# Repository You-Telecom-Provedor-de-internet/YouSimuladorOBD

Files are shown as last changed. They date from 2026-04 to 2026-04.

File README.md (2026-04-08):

# YouSimuladorOBD - Emulador OBD-II com ESP32

Simulador OBD-II baseado em `ESP32` para validar scanners, adaptadores e aplicativos automotivos reais em bancada e evoluir para uma placa dedicada orientada a produto.

O projeto atual entrega:

- `7` protocolos OBD-II selecionaveis em runtime
- barramento `CAN` validado com scanner real
- barramento `K-Line` validado com `L9637D`
- `Web UI`, `API REST`, `WebSocket`, `mDNS` e `OTA`
- odometro persistente e camada diagnostica com `Mode 02`, `03`, `04`, `06` e `09`

Importante:

- o simulador nao usa Bluetooth proprio nesta revisao
- a validacao de bancada foi feita com adaptadores externos, como `OBDLink MX+` e `ELM327`

## Protocolos suportados

| Enum | Protocolo | Fisica | Estado |
|---|---|---|---|
| `0` | `CAN 11b 500k` | CAN | Validado |
| `1` | `CAN 11b 250k` | CAN | Validado |
| `2` | `CAN 29b 500k` | CAN | Validado |
| `3` | `CAN 29b 250k` | CAN | Validado |
| `4` | `ISO 9141-2` | K-Line | Validado |
| `5` | `KWP 5-baud` | K-Line | Validado |
| `6` | `KWP Fast` | K-Line | Validado |

## Hardware validado

- `ESP32 DevKit` 38 pinos
- `SN65HVD230` para CAN
- `L9637D` para K-Line
- `LM2596` para `12V -> 5V`
- `OLED SH1107 128x128`
- `KY-040`
- `6` botoes + `3` bits de DIP + `3` LEDs de status

## RevA PCB congelada

A `RevA` da placa foi congelada como:

- `carrier para ESP32 DevKit 38 pinos`
- `OLED SH1107` em modulo por header
- `KY-040` em modulo por header
- `LM2596` mantido como modulo ou footprint equivalente de baixo risco

Ou seja, nesta revisao a PCB nao integra `ESP32-WROOM` soldado diretamente. O objetivo e preservar o modulo validado em bancada, reduzir risco da primeira placa e acelerar a ida para layout.

## Fase atual do projeto

Estado atual consolidado:

- prototipo fisico montado e testado com `ESP32 DevKit`, `L9637D`, `SN65HVD230`, `OLED` e interface local
- `7` protocolos suportados com aceite operacional, incluindo `KWP 5-baud`
- arquitetura `RevA` mantida como `carrier para ESP32 DevKit 38 pinos`

Objetivo desta proxima fase:

- capturar e fechar a `PCB RevA`
- reduzir improvisos de bancada e transformar a arquitetura atual em hardware repetivel
- preparar a plataforma para virar produto com foco em robustez eletrica, montagem, teste e manutencao

## Documentacao canonica

Use estes arquivos como ponto de entrada principal:

- [Arquitetura canonica](docs/arquitetura.md)
- [Hardware consolidado](docs/hardware.md)
- [Pinout canonico](docs/pinout.md)
- [Manual de operacao](docs/manual-operacao.md)
- [Montagem K-Line com L9637D](docs/kline-l9637d-montagem.md)
- [Diagrama eletrico e handoff PCB](docs/diagrama-eletrico-pcb.md)
- [RevA carrier para ESP32 DevKit](docs/reva-carrier-esp32-devkit.md)
- [Mapa final de GPIO da RevA](docs/mapa-gpio-reva.md)
- [Guia executivo para PCB](docs/engenharia-pcb.md)
- [Firmware - README local](firmware/README.md)
- [Hardware - README local](hardware/README.md)
- [Esquematico conceitual](hardware/schematic/esquematico-conceitual.md)
- [Netlist humana](hardware/schematic/netlist-humana.md)
- [BOM preliminar](hardware/schematic/bom-preliminar.csv)
- [Requisitos de layout PCB](hardware/pcb/requisitos-layout.md)
- [Hardware - Pacote para PCB](hardware/pcb-handoff/README.md)
- [Hardware - KiCad RevA](hardware/kicad/revA/README.md)

## Build e gravacao

```bash
cd firmware
pio run
pio run -t upload
pio run -t uploadfs
```

Para detalhes do firmware e das dependencias:

- [firmware/README.md](firmware/README.md)

## Como evoluir a RevA para esquematico/PCB real

1. Ler [docs/hardware.md](docs/hardware.md) e [docs/pinout.md](docs/pinout.md).
2. Capturar ou revisar a conectividade com base em:
   - [hardware/schematic/esquematico-conceitual.md](hardware/schematic/esquematico-conceitual.md)
   - [hardware/schematic/netlist-humana.md](hardware/schematic/netlist-humana.md)
   - [hardware/schematic/bom-preliminar.csv](hardware/schematic/bom-preliminar.csv)
3. Aplicar as regras de layout em [hardware/pcb/requisitos-layout.md](hardware/pcb/requisitos-layout.md).
4. Comparar com o handoff congelado em [hardware/pcb-handoff/](hardware/pcb-handoff/).
5. Continuar a captura nativa a partir de [hardware/kicad/revA/](hardware/kicad/revA/).
6. Fechar a `RevA` com criterio de produto:
   - protecao automotiva definitiva
   - conectividade mecanica repetivel
   - pontos de teste
   - montagem e manutencao previsiveis

## Estrutura de pastas

```text
YouSimuladorOBD/
|- README.md
|- assets/
|  `- validation/
|- docs/
|  |- arquitetura.md
|  |- hardware.md
|  |- pinout.md
|  |- manual-operacao.md
|  |- kline-l9637d-montagem.md
|  |- diagrama-eletrico-pcb.md
|  |- reva-carrier-esp32-devkit.md
|  |- mapa-gpio-reva.md
|  |- engenharia-pcb.md
|  `- ota-manifest.example.json
|- firmware/
|  |- README.md
|  |- include/
|  |- src/
|  |- data/
|  `- platformio.ini
|- hardware/
|  |- README.md
|  |- bom/
|  |- cad/
|  |- kicad/revA/
|  |- pcb/
|  |- pcb-handoff/
|  `- schematic/
|- tools/
`- wokwi/
```

## Observacoes importantes

- os documentos canonicos desta rodada sao `docs/hardware.md`, `docs/pinout.md`, `docs/engenharia-pcb.md` e os arquivos em `hardware/schematic/`
- `hardware/pcb-handoff/` e `hardware/kicad/revA/` continuam sendo baseline tecnico importante para o engenheiro de PCB
- os artefatos de validacao de bancada que estavam soltos na raiz foram movidos para `assets/validation/`
- a integracao com o laboratorio Codex permanece no repositorio do plugin `YOU OBD Lab`, separado deste repositorio
- a operacao diaria do simulador, incluindo OTA e credencial fixa da API, esta em `docs/manual-operacao.md`

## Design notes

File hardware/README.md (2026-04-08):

# Hardware

Este diretorio concentra os artefatos de hardware, mecanica, handoff e EDA do `YouSimuladorOBD`.

## Baseline da RevA

A `RevA` atual deve ser entendida como:

- `carrier para ESP32 DevKit 38 pinos`
- `SN65HVD230` para CAN
- `L9637D` para K-Line
- `OLED SH1107` via header
- `KY-040` via header
- buck `12V -> 5V` de baixo risco baseado em `LM2596` ou equivalente

## Funcao das pastas

### `kicad/`

- bootstrap EDA nativo da `RevA`
- referencia para continuar a captura do esquematico real

### `pcb-handoff/`

- netlist e BOM de handoff congeladas em CSV
- baseline de transicao entre bancada e captura formal em EDA

### `schematic/`

- material textual canonico desta rodada
- contem:
  - `esquematico-conceitual.md`
  - `netlist-humana.md`
  - `bom-preliminar.csv`

### `pcb/`

- regras e requisitos de layout para a placa

### `cad/`

- referencia mecanica e arquivos de case/painel

### `bom/`

- registros auxiliares de status de BOM

## Fluxo recomendado para engenharia

1. comecar por `../docs/hardware.md`
2. ler `../docs/pinout.md`
3. usar `schematic/` como base textual atual
4. comparar com `pcb-handoff/`
5. continuar a captura em `kicad/revA/`

## Observacao importante

O fato de algo existir em `hardware/` nao significa automaticamente que esteja confirmado pelo firmware.

Para classificacao tecnica, usar a regra:

- `confirmado no codigo`
- `confirmado na documentacao/EDA existente`
- `inferido / hipotese`

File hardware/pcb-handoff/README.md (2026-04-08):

# Pacote de Handoff para PCB

Este diretorio contem o material tecnico consolidado para o engenheiro capturar o esquema da placa.

## Arquivos

- `netlist-rev-a.csv`
  - nets eletricas consolidadas
- `bom-rev-a.csv`
  - lista base de componentes para a revisao A

## Documento mestre

O documento principal do handoff e:

- `docs/diagrama-eletrico-pcb.md`
- `docs/engenharia-pcb.md`

## Captura nativa iniciada

O projeto tambem ja possui um bootstrap nativo no `KiCad`:

- `hardware/kicad/revA/YouSimuladorOBD_RevA.kicad_sch`

Esse conjunto nao substitui o handoff consolidado, mas acelera a continuacao da captura pelo engenheiro.

## Escopo

Este pacote descreve a topologia eletrica validada em bancada:

- `ESP32 DevKit 38 pinos` em carrier RevA
- `LM2596`
- `SN65HVD230`
- `L9637D`
- `OLED`
- botoes, encoder, DIP e LEDs

## Decisao congelada da RevA

A revisao `RevA` fica congelada como:

- `carrier para ESP32 DevKit 38 pinos`
- `OLED` via header
- `KY-040` via header
- `LM2596` por modulo ou footprint equivalente

O pacote desta pasta e o bootstrap em `KiCad` devem ser interpretados nessa arquitetura.

## Observacao importante

Este pacote complementa `hardware/schematic/` e o bootstrap em `hardware/kicad/revA/`; os tres devem permanecer coerentes com os documentos canonicos em `docs/`.

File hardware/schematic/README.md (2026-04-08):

# Material Canonico de Esquematico

Esta pasta agora e o ponto canonico dos artefatos textuais de esquematico do projeto.

## Use esta pasta para

- `esquematico-conceitual.md`
  - esquematico textual por blocos da `RevA`
- `netlist-humana.md`
  - conectividade humana consolidada para engenharia
- `bom-preliminar.csv`
  - lista preliminar de componentes para captura e layout

## Fontes principais a usar junto com esta pasta

- `docs/hardware.md`
- `docs/pinout.md`
- `docs/engenharia-pcb.md`
- `hardware/pcb-handoff/`
- `hardware/kicad/revA/`

## Regra pratica

Para divergencias ou duvidas de engenharia:

1. priorizar firmware atual para pinagem e dependencias logicas
2. priorizar `docs/hardware.md` e `docs/pinout.md` para documentacao canonica
3. usar `hardware/pcb-handoff/` e `hardware/kicad/revA/` como baseline de handoff e EDA

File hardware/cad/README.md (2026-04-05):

# CAD e Impressao 3D

Este diretorio concentra os primeiros ativos mecanicos do projeto.

## Primeira peca teste

`bench_case_revA_base`

Objetivo:

- servir como primeira peca de validacao na `Creality K1`
- testar tolerancias, rigidez e volume util para a futura placa do `YouSimuladorOBD`
- oferecer uma base aberta tipo `bench tray`, mais segura para a fase atual do hardware do que um gabinete fechado definitivo

Arquivos gerados:

- `freecad/bench_case_revA_base.FCStd`
- `freecad/bench_case_revA_base.step`
- `freecad/bench_case_revA_base.stl`
- `renders/bench_case_revA_base.png`

## Segunda peca teste

`bench_case_revA_lid_ui`

Objetivo:

- criar a tampa inicial para a bandeja `revA`
- aproximar o frontal do hardware real da UI local
- testar leitura do `OLED SH1107 128x128` atraves de uma janela quadrada
- testar a disposicao real de botoes dedicados e do encoder rotativo

Arquivos gerados:

- `freecad/bench_case_revA_lid_ui.FCStd`
- `freecad/bench_case_revA_lid_ui.step`
- `freecad/bench_case_revA_lid_ui.stl`
- `renders/bench_case_revA_lid_ui.png`

Caracteristicas:

- tampa tipo `cap` com labio interno de encaixe
- janela quadrada central para `OLED SH1107 128x128`
- rebaixo frontal ao redor do display
- fileira de 6 botoes: `PREV`, `NEXT`, `UP`, `DOWN`, `OK`, `PROTO`
- furo separado para o encoder rotativo `KY-040`
- geometria ainda parametrica, mas agora alinhada com a UI implementada no firmware

## Compatibilidade com o projeto real

O handoff eletrico da PCB ja inclui o display e o encoder:

- `hardware/pcb-handoff/bom-rev-a.csv`
  - `DISP1 = OLED SH1107 128x128`
  - `ENC1 = Rotary encoder KY-040`
- `hardware/pcb-handoff/netlist-rev-a.csv`
  - `ENC_A`, `ENC_B`, `ENC_SW`
  - `I2C_SDA`, `I2C_SCL`

Ou seja, esta tampa passa a refletir melhor o que a placa real devera acomodar.

## Assuncoes desta revisao

Como a PCB final ainda esta em captura, esta primeira peca usa um envelope mecanico conservador:

- area util de placa: `120 x 85 mm`
- folga interna lateral: `3 mm`
- espessura da base: `3 mm`
- espessura de parede: `3 mm`
- altura de parede: `22 mm`
- standoffs internos para parafuso `M3`

Isso torna a peca util como:

- bandeja de bancada para a eletronica atual
- base de teste de impressao
- ponto de partida para o gabinete final da PCB

## Ferramentas usadas

- `FreeCAD 1.1`
- `Blender 5.1` para preview

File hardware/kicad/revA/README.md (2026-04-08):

# KiCad RevA

Bootstrap nativo do projeto no `KiCad`, criado a partir do handoff validado em bancada.

## Escopo desta captura inicial

Esta revisao ainda nao e o esquematico completo final. Ela entrega:

- folha raiz nativa do `KiCad`
- separacao por blocos funcionais
- pontos de entrada claros para o engenheiro continuar a captura
- referencia mecanica do frontal de `OLED + KY-040 + 6 botoes`
- arquitetura congelada da `RevA` como `carrier para ESP32 DevKit 38 pinos`

## Arquivos

- `YouSimuladorOBD_RevA.kicad_sch`
  - folha raiz
- `power_input.kicad_sch`
  - entrada OBD, fusivel e buck
- `esp32_core.kicad_sch`
  - MCU, GPIOs e mapa funcional
- `obd_transceivers.kicad_sch`
  - `SN65HVD230` e `L9637D`
- `ui_local.kicad_sch`
  - `OLED SH1107`, `KY-040`, botoes, DIP e LEDs
- `ui-panel-reference.csv`
  - coordenadas base do painel frontal da tampa de teste
- `esp32-devkit38-carrier-reference.csv`
  - envelope, headers e keepouts do `ESP32 DevKit` na carrier
- `erc-report.txt`
  - validacao inicial do bootstrap com `0` erros e `0` warnings

## Fonte tecnica

Os dados eletricos consolidados continuam sendo:

- `docs/diagrama-eletrico-pcb.md`
- `docs/reva-carrier-esp32-devkit.md`
- `docs/mapa-gpio-reva.md`
- `hardware/pcb-handoff/netlist-rev-a.csv`
- `hardware/pcb-handoff/bom-rev-a.csv`

## Observacao

Esta captura foi iniciada para que o engenheiro ja possa trabalhar em arquivo EDA nativo sem depender apenas do handoff em `Markdown + CSV`.

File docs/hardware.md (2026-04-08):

# Hardware Consolidado

Documento canonico de consolidacao eletrica do `YouSimuladorOBD`.

Objetivo:

- reunir em um unico lugar o que o firmware realmente exige do hardware
- separar o que esta confirmado no codigo do que vem de documentacao e EDA existente
- registrar explicitamente o que ainda e inferido ou depende de confirmacao antes do esquematico final

Fontes principais usadas nesta consolidacao:

- `firmware/include/config.h`
- `firmware/src/main.cpp`
- `firmware/src/protocols/can_protocol.cpp`
- `firmware/src/protocols/kline_protocol.cpp`
- `firmware/src/protocols/protocol_init.cpp`
- `firmware/src/web/ui_init.cpp`
- `firmware/src/web/web_server.cpp`
- `firmware/platformio.ini`
- `docs/pinout.md`
- `docs/kline-l9637d-montagem.md`
- `docs/diagrama-eletrico-pcb.md`
- `docs/engenharia-pcb.md`
- `docs/reva-carrier-esp32-devkit.md`
- `docs/mapa-gpio-reva.md`
- `hardware/pcb-handoff/bom-rev-a.csv`
- `hardware/pcb-handoff/netlist-rev-a.csv`
- `hardware/kicad/revA/README.md`
- `hardware/kicad/revA/erc-report.txt`
- `hardware/kicad/revA/*.kicad_sch`
- `wokwi/diagram.json`

## Visao geral funcional da placa

O `YouSimuladorOBD` e uma placa de bancada para emular uma ECU OBD-II usando um `ESP32 DevKit` 38 pinos como MCU principal. A placa precisa responder a scanners reais nos barramentos:

- `CAN` usando o controlador `TWAI` nativo do ESP32 e um transceiver `SN65HVD230`
- `K-Line` usando `UART1` do ESP32 e um transceiver `L9637D`

Tambem precisa oferecer:

- interface local com `OLED SH1107 128x128`
- `6 botoes`
- `encoder KY-040`
- `DIP switch` de 3 bits para selecao rapida de protocolo
- `LED_TX` externo opcional e o LED onboard do DevKit
- `Wi-Fi`, `Web UI`, `WebSocket`, `API REST`, `mDNS` e `OTA` pela rede

Arquitetura alvo desta rodada:

- `RevA` congelada como `carrier board para ESP32 DevKit 38 pinos`
- sem migracao para `ESP32-WROOM` integrado nesta rodada

## Blocos funcionais

| Bloco | Descricao | Classificacao dominante |
|---|---|---|
| MCU | `ESP32 DevKit` 38 pinos com FreeRTOS/Arduino, TWAI, UART1, I2C, Wi-Fi e LittleFS | confirmado no codigo + confirmado na documentacao/EDA existente |
| Entrada automotiva | `OBD-II J1962` com `+12V`, `GND`, `CANH`, `CANL`, `K-Line` | confirmado na documentacao/EDA existente |
| Fonte primaria | `+12V OBD -> fusivel -> buck 12V para 5V` | confirmado na documentacao/EDA existente |
| Fonte logica | `5V` para `VIN` do DevKit e `+3V3_AUX` dedicado para perifericos | confirmado na documentacao/EDA existente |
| CAN | `SN65HVD230` em `+3V3_AUX` ligado ao TWAI nativo do ESP32 | confirmado no codigo + confirmado na documentacao/EDA existente |
| K-Line | `L9637D` com `VS` em `+12V`, logica em `+3V3_AUX`, `K` no OBD e bias passivo dedicado | confirmado no codigo + confirmado na documentacao/EDA existente |
| UI local | `OLED SH1107`, `KY-040`, `6 botoes`, `DIP`, `LED_TX` opcional | confirmado no codigo + confirmado na documentacao/EDA existente |
| Rede e web | `Wi-Fi AP/STA`, `mDNS`, `ESPAsyncWebServer`, `LittleFS`, `OTA` | confirmado no codigo |
| EDA baseline | handoff em CSV e bootstrap em `KiCad RevA` com `0` erros e `0` warnings de ERC | confirmado na documentacao/EDA existente |

## Entradas

| Entrada | Origem | Observacao | Classificacao |
|---|---|---|---|
| `+12V_OBD` | `J1 pin 16` | alimenta o buck e o `VS` do `L9637D` | confirmado na documentacao/EDA existente |
| `GND` | `J1 pin 4` e `J1 pin 5` | referencia comum do sistema | confirmado na documentacao/EDA existente |
| `CANH/CANL` | `J1 pin 6` e `J1 pin 14` | trafego OBD sobre CAN | confirmado na documentacao/EDA existente |
| `K-Line` | `J1 pin 7` | trafego OBD em `ISO 9141-2`, `KWP 5-baud` e `KWP Fast` | confirmado no codigo + confirmado na documentacao/EDA existente |
| botoes locais | `GPIO32`, `33`, `25`, `26`, `27`, `18` | entradas com `INPUT_PULLUP`, botoes para `GND` | confirmado no codigo |
| encoder | `GPIO14`, `13`, `19` | `A`, `B` e `SW` | confirmado no codigo |
| DIP de protocolo | `GPIO34`, `35`, `36` | somente entrada; exigem pull-up externo para `+3V3_AUX` | confirmado no codigo + confirmado na documentacao/EDA existente |
| USB do DevKit | conector do modulo comercial | usado para gravacao e serial debug | confirmado na documentacao/EDA existente |

## Saidas

| Saida | Destino | Observacao | Classificacao |
|---|---|---|---|
| resposta OBD em CAN | scanner no `J1 pin 6/14` | via `SN65HVD230` | confirmado no codigo + confirmado na documentacao/EDA existente |
| resposta OBD em K-Line | scanner no `J1 pin 7` | via `L9637D` | confirmado no codigo + confirmado na documentacao/EDA existente |
| display local | modulo `OLED SH1107` | I2C em `GPIO21/22` | confirmado no codigo + confirmado na documentacao/EDA existente |
| LED de status externo | `GPIO23` | `LED_TX` opcional para trafego | confirmado no codigo + confirmado na documentacao/EDA existente |
| LED heartbeat | `GPIO2` | LED onboard do DevKit, nao detalhado na carrier | confirmado no codigo |
| Wi-Fi/web | AP/STA com web UI, API e OTA | interface sem fio do ESP32 | confirmado no codigo |

## Interfaces externas

| Interface | Implementacao | Status |
|---|---|---|
| `OBD-II J1962` | `J1` com pinos `4/5/6/7/14/16` usados | confirmado na documentacao/EDA existente |
| `CAN` | `TWAI` do ESP32 + `SN65HVD230` | confirmado no codigo + confirmado na documentacao/EDA existente |
| `K-Line` | `UART1` do ESP32 + `L9637D` | confirmado no codigo + confirmado na documentacao/EDA existente |
| `I2C` | `GPIO21 SDA` e `GPIO22 SCL` para o OLED | confirmado no codigo |
| `USB serial/programacao` | USB do `ESP32 DevKit` | confirmado na documentacao/EDA existente |
| `Wi-Fi 2.4 GHz` | AP/STA do ESP32 | confirmado no codigo |
| `mDNS` | hostname configuravel, default `youobd.local` | confirmado no codigo |
| `BLE/Bluetooth embarcado` | nao usado nesta revisao | confirmado no codigo por ausencia de uso ativo no build e no firmware atual |

## Alimentacao

### Topologia consolidada

```text
J1 pin 16 (+12V OBD)
  -> F1
  -> +12V_PROT
  -> U1 buck 12V -> 5V
  -> U3 L9637D pin 7 (VS)
  -> RK1 510R para a linha K
  -> RLI1 10k para o pino LI do L9637D

J1 pin 4 / pin 5 (GND)
  -> GND comum

U1 OUT+
  -> +5V_SYS
  -> VIN / 5V do ESP32 DevKit
  -> U4 regulador 3.3V dedicado

U4 OUT
  -> +3V3_AUX
  -> U2 SN65HVD230
  -> U3 L9637D VCC logico
  -> OLED SH1107
  -> ENC1 KY-040
  -> pull-ups do DIP
```

### Observacoes

- O firmware depende implicitamente de o `ESP32 DevKit` receber `5V` em `VIN` e do rail `+3V3_AUX` alimentar os perifericos de forma estavel.
- `+3V3_AUX` deve permanecer separado do pino `3V3` de saida do `ESP32 DevKit`.
- O codigo nao define nenhuma medicao de tensao de entrada nem supervisao analogica da fonte. Logo, a robustez da entrada `+12V` fica a cargo da eletrica da placa.
- A corrente total do sistema nao esta formalizada em documento eletrico fechado; isso ainda precisa ser confirmado antes do esquematico final se houver mudanca de buck ou integracao futura do MCU.

## Protecao eletrica

| Item | Estado | Origem | Observacao |
|---|---|---|---|
| `F1` fusivel de entrada `1A` | confirmado como baseline de handoff | docs + `hardware/pcb-handoff` + KiCad bootstrap | nao ha part number final congelado |
| TVS na entrada `+12V` | recomendado e registrado | `docs/diagrama-eletrico-pcb.md` e `docs/engenharia-pcb.md` | nao confirmado como implementado na bancada base |
| protecao contra inversao de polaridade | recomendada | `docs/diagrama-eletrico-pcb.md` | topologia final nao fechada |
| ESD no conector OBD | nao encontrado como item fechado | inferido / hipotese | recomendavel para PCB automotiva, principalmente nas linhas externas |
| terminacao CAN `120R` por jumper ou DNP | recomendada | docs + `hardware/pcb-handoff/bom-rev-a.csv` | nao ha prova no codigo; no breakout de bancada a terminacao pode ja existir |
| desacoplamento local do `L9637D` | confirmado | docs + `hardware/pcb-handoff` + KiCad bootstrap | `CK1` e `CK2` de `100nF` obrigatorios |
| desacoplamento local do `SN65HVD230` | confirmado como baseline de handoff | `hardware/pcb-handoff/bom-rev-a.csv` | `CCAN1 100nF` |

### Fechamento recomendado de protecao para a RevA

Os itens abaixo nao estao confirmados no codigo. Eles sao recomendacoes de engenharia para transformar a `RevA` em uma PCB mais robusta e mais objetiva para compra e montagem.

| Funcao | Componente recomendado | Classificacao | Observacao pratica |
|---|---|---|---|
| fusivel de entrada | `F1 1A` | confirmado na documentacao/EDA existente + recomendacao de fechamento | manter como primeira barreira da linha `+12V_OBD` |
| TVS da entrada `+12V` | `SMCJ24A` unidirecional | inferido / hipotese fortemente recomendada | encapsulamento `DO-214AB`; fica antes do buck e do `VS` do `L9637D` |
| ESD para `CANH/CANL` | `PESD2CAN24LT-Q` | inferido / hipotese fortemente recomendada | componente automotivo de 2 linhas; colocar junto de `J1` |
| ESD/surge para `K-Line` | `ESDLIN1524BJ` | inferido / hipotese fortemente recomendada | otimizado para barramentos tipo `LIN/CXPI`; serve bem como referencia para a linha `K` |
| reversao de polaridade / load disconnect | `LM74502-Q1` + `2 x MOSFET N` back-to-back | inferido / hipotese fortemente recomendada | solucao de baixa perda para uso automotivo; os MOSFETs ainda precisam ser fechados pela corrente alvo |

Observacoes:

- Para prototipo rapido de bancada, um diodo Schottky em serie pode funcionar como protecao simples de reversao, mas nao e a recomendacao principal para a PCB final por perda termica e queda de tensao.
- As protecoes acima devem ser tratadas como adicao recomendada sobre o baseline atual de bancada/handoff, nao como itens ja comprovados pelo firmware.

## Componentes provaveis

| RefDes | Componente provavel | Papel | Classificacao |
|---|---|---|---|
| `MCU1` | `ESP32 DevKit 38p` | MCU principal | confirmado na documentacao/EDA existente |
| `U1` | modulo `LM2596` ou buck equivalente | `12V -> 5V` | confirmado na documentacao/EDA existente |
| `U4` | regulador `3.3V` dedicado | gera `+3V3_AUX` para perifericos | confirmado na documentacao/EDA existente |
| `U2` | `SN65HVD230` | transceiver CAN 3V3 | confirmado na documentacao/EDA existente |
| `U3` | `L9637D` | transceiver K-Line | confirmado na documentacao/EDA existente |
| `TVS1` | `SMCJ24A` | protecao de surto na entrada `+12V` | inferido / hipotese fortemente recomendada |
| `D_ESD_CAN1` | `PESD2CAN24LT-Q` | protecao ESD de `CANH/CANL` | inferido / hipotese fortemente recomendada |
| `D_ESD_K1` | `ESDLIN1524BJ` | protecao ESD/surge da `K-Line` | inferido / hipotese fortemente recomendada |
| `UREV1` | `LM74502-Q1` + MOSFETs externos | protecao de reversao de polaridade e chaveamento de entrada | inferido / hipotese fortemente recomendada |
| `J1` | conector `OBD-II` 16 pinos | interface automotiva externa | confirmado na documentacao/EDA existente |
| `DISP1` | modulo `OLED SH1107 128x128` | interface local | confirmado na documentacao/EDA existente |
| `ENC1` | `KY-040` | encoder da UI | confirmado na documentacao/EDA existente |
| `SW1` | DIP switch 3 posicoes | boot fallback de protocolo | confirmado na documentacao/EDA existente |
| `SW2-SW7` | botoes momentaneos | UI local | confirmado na documentacao/EDA existente |
| `D3` | LED externo opcional | `LED_TX` | confirmado na documentacao/EDA existente |
| `JMCU1/JMCU2` | headers femea `1x19` | carrier do DevKit | confirmado na documentacao/EDA existente |
| `JDISP1` | header `1x4` | modulo OLED | confirmado na documentacao/EDA existente |
| `JENC1` | header `1x5` | modulo encoder | confirmado na documentacao/EDA existente |

## Dependencias eletricas implicitas

Estas dependencias nao dependem de preferencia de software; elas sao impostas pelo hardware ou pelo proprio firmware atual.

1. `GPIO34`, `GPIO35` e `GPIO36` sao somente entrada e sem `pull-up` interno.
   - efeito: o `DIP` precisa de `pull-up` externo para `+3V3_AUX`
   - base: `config.h`, `main.cpp`, `docs/pinout.md`, `hardware/pcb-handoff/netlist-rev-a.csv`

2. A linha `K-Line` precisa de nivel de idle alto estavel em `+12V`.
   - efeito: `RK1 510R` entre `K` e `VS` e `RLI1 10k` entre `LI` e `VS` deixam de ser opcionais para reproduzir a bancada validada
   - base: `docs/kline-l9637d-montagem.md`, `docs/diagrama-eletrico-pcb.md`, `hardware/pcb-handoff`

3. O `L9637D` precisa de dois dominios de alimentacao.
   - `VCC` logico em `+3V3_AUX`
   - `VS` automotivo em `+12V`
   - base: `docs/kline-l9637d-montagem.md`, `docs/diagrama-eletrico-pcb.md`, `hardware/pcb-handoff/netlist-rev-a.csv`

4. O `SN65HVD230` precisa operar em `+3V3_AUX` e ficar com `RS` em `GND` para o modo rapido registrado no handoff.
   - base: `docs/pinout.md`, `hardware/pcb-handoff/netlist-rev-a.csv`

5. A regiao de antena do `ESP32 DevKit` exige `keepout` de cobre e componentes.
   - base: `docs/reva-carrier-esp32-devkit.md`

6. O `OLED` depende de barramento `I2C` em `400 kHz` configurado no firmware e de `+3V3_AUX` bem desacoplado.
   - base: `ui_init.cpp`
   - implicacao: manter trilhas curtas e return path limpo para evitar instabilidade visual

7. O buck e o resistor `RK1` precisam de cuidado termico.
   - base: `docs/diagrama-eletrico-pcb.md`
   - implicacao: placement e cobre devem considerar dissipacao, especialmente para `RK1`

## Itens confirmados no codigo

- `PIN_CAN_TX = GPIO4` e `PIN_CAN_RX = GPIO5`
- `PIN_KLINE_TX = GPIO17` e `PIN_KLINE_RX = GPIO16`
- `K-Line` usa `UART1` a `10400 baud`
- `TWAI` do ESP32 e usado para os protocolos CAN
- `OLED` usa `GPIO21 SDA`, `GPIO22 SCL`, endereco `0x3C`
- `6 botoes` usam `GPIO32`, `33`, `25`, `26`, `27`, `18` com `INPUT_PULLUP`
- `encoder` usa `GPIO14`, `13`, `19`
- `DIP` usa `GPIO34`, `35`, `36`
- `LED_TX` externo usa `GPIO23`
- o `LED` onboard usa `GPIO2`
- `Wi-Fi`, `mDNS`, `LittleFS`, `ESPAsyncWebServer`, `OTA` e autenticacao web/API estao ativos
- nao ha uso ativo de `BLE` ou `Bluetooth Classic` no firmware atual desta revisao

## Itens confirmados na documentacao/EDA existente

- `RevA` congelada como `carrier para ESP32 DevKit 38 pinos`
- `SN65HVD230` como transceiver CAN
- `L9637D` como transceiver K-Line
- `LM2596` como baseline de buck `12V -> 5V`
- regulador `3.3V` dedicado como fonte de `+3V3_AUX` para perifericos
- conector `OBD-II` com uso dos pinos `4`, `5`, `6`, `7`, `14`, `16`
- `RK1 510R`, `RLI1 10k`, `CK1 100nF`, `CK2 100nF` como conjunto obrigatorio do `L9637D`
- `RCAN1 120R` como terminacao CAN opcional por jumper ou `DNP`
- `OLED SH1107 128x128` via header
- `KY-040` via header
- `2 x 1x19` como carrier do DevKit
- bootstrap `KiCad RevA` com folhas `Power_Input`, `ESP32_Core`, `OBD_Transceivers` e `UI_Local`
- `ERC report` com `0` erros e `0` warnings

## Itens inferidos / hipotese

- TVS exata de entrada, encapsulamento e potencia ainda nao estao congelados
- a familia escolhida para a TVS de entrada foi fechada como recomendacao em `SMCJ24A`, mas a validacao final contra o ambiente real do produto ainda precisa ser feita
- a topologia recomendada para reversao foi fechada em `LM74502-Q1` com MOSFETs externos, mas os MOSFETs e os resistores de apoio ainda precisam ser definidos pela corrente alvo
- o part number exato do `ESP32 DevKit 38 pinos` comercial ainda precisa ser confirmado antes de liberar footprint final
- o part number exato do regulador dedicado de `+3V3_AUX` ainda precisa ser congelado
- footprint final do `OLED SH1107` e do `KY-040` depende do modulo real escolhido para a RevA
- o ponto exato de amarracao entre `signal GND` e `chassis GND` no layout final ainda nao esta descrito em detalhe
- a terminacao CAN pode ter existido no breakout de bancada; na PCB final ela deve ser explicitada por componente selecionavel
- nao ha, nas fontes lidas, definicao eletrica final para `L-Line` alem de `NC`

## Conflitos e divergencias identificadas

1. Narrativas antigas de UI local foram removidas desta rodada.
   - efeito: usar `ui_init.cpp` como fonte primaria de comportamento real da UI local

2. Narrativas antigas de selecao por serial USB foram removidas desta rodada.
   - efeito: no estado atual o firmware usa `NVS`, `DIP` e mudanca por UI/web

3. O firmware confirma pinagem e barramentos, mas nao confirma sozinho todos os componentes fisicos do carrier RevA.
   - efeito: para esquematico/PCB usar sempre a combinacao `codigo + docs/diagrama-eletrico-pcb.md + docs/engenharia-pcb.md + docs/reva-carrier-esp32-devkit.md + pcb-handoff + KiCad RevA`

4. Protecoes automotivas adicionais aparecem como recomendacao de engenharia, nao como baseline eletrico comprovado pelo firmware.
   - efeito: registrar essas protecoes como obrigatorias para PCB robusta, mas nao como "confirmadas no codigo"

## Riscos e lacunas tecnicas

- definir TVS de entrada, protecao contra inversao de polaridade e estrategia de ESD antes do esquematico final
- confirmar o `ESP32 DevKit` comercial exato antes de congelar footprints e keepouts
- confirmar o modulo real do `OLED SH1107` e do `KY-040` antes do layout final
- formalizar corrente maxima esperada do sistema se o buck deixar de ser modulo pronto
- revisar dissipacao de `RK1 510R` e posicionamento termico
- decidir se a RevA tera conector OBD de placa, chicote ou ambos
- documentar a estrategia final de ponto de teste e depuracao de bancada
- tratar `SSID`, `hostname` e credenciais hardcoded como risco operacional/documental; nao foram alterados nesta rodada

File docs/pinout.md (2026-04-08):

# Pinout Canonico

Documento canonico de pinagem e sinais do `YouSimuladorOBD`.

Regra de interpretacao:

- `confirmado no codigo`: a associacao esta implementada diretamente no firmware atual
- `confirmado na documentacao/EDA existente`: a associacao vem do handoff, docs tecnicas ou bootstrap KiCad
- `inferido / hipotese`: a associacao e plausivel, mas ainda depende de confirmacao fisica ou de escolha final de componente

Fontes principais:

- `firmware/include/config.h`
- `firmware/src/main.cpp`
- `firmware/src/protocols/can_protocol.cpp`
- `firmware/src/protocols/kline_protocol.cpp`
- `firmware/src/web/ui_init.cpp`
- `docs/hardware.md`
- `docs/kline-l9637d-montagem.md`
- `docs/diagrama-eletrico-pcb.md`
- `docs/mapa-gpio-reva.md`
- `hardware/pcb-handoff/netlist-rev-a.csv`

## Sinais do ESP32 usados pelo projeto

| Sinal | GPIO / pino fisico | Funcao | Origem da confirmacao | Observacoes eletricas | Classificacao |
|---|---|---|---|---|---|
| `CAN_TX_LOGIC` | `GPIO4` | `TWAI TX` para `U2 SN65HVD230 TXD` | `config.h` + `can_protocol.cpp` + `hardware/pcb-handoff/netlist-rev-a.csv` | logica em rail `+3V3_AUX`; ativo nos protocolos CAN | confirmado no codigo |
| `CAN_RX_LOGIC` | `GPIO5` | `TWAI RX` vindo de `U2 SN65HVD230 RXD` | `config.h` + `can_protocol.cpp` + `hardware/pcb-handoff/netlist-rev-a.csv` | logica em rail `+3V3_AUX`; ativo nos protocolos CAN | confirmado no codigo |
| `K_TX_LOGIC` | `GPIO17` | `UART1 TX` para `U3 L9637D pin 4` | `config.h` + `kline_protocol.cpp` + `docs/kline-l9637d-montagem.md` | precisa manter idle alto coerente com a interface K-Line | confirmado no codigo |
| `K_RX_LOGIC` | `GPIO16` | `UART1 RX` vindo de `U3 L9637D pin 1` | `config.h` + `kline_protocol.cpp` + `docs/kline-l9637d-montagem.md` | entrada de retorno da K-Line | confirmado no codigo |
| `I2C_SDA` | `GPIO21` | `OLED SH1107 SDA` | `config.h` + `ui_init.cpp` + `hardware/pcb-handoff/netlist-rev-a.csv` | I2C em `400 kHz`; modulo em `+3V3_AUX` | confirmado no codigo |
| `I2C_SCL` | `GPIO22` | `OLED SH1107 SCL` | `config.h` + `ui_init.cpp` + `hardware/pcb-handoff/netlist-rev-a.csv` | I2C em `400 kHz`; modulo em `+3V3_AUX` | confirmado no codigo |
| `BTN_PREV` | `GPIO32` | botao `PREV` | `config.h` + `ui_init.cpp` | `INPUT_PULLUP`; chave para `GND` | confirmado no codigo |
| `BTN_NEXT` | `GPIO33` | botao `NEXT` | `config.h` + `ui_init.cpp` | `INPUT_PULLUP`; chave para `GND` | confirmado no codigo |
| `BTN_UP` | `GPIO25` | botao `UP` | `config.h` + `ui_init.cpp` | `INPUT_PULLUP`; chave para `GND` | confirmado no codigo |
| `BTN_DOWN` | `GPIO26` | botao `DOWN` | `config.h` + `ui_init.cpp` | `INPUT_PULLUP`; chave para `GND` | confirmado no codigo |
| `BTN_SELECT` | `GPIO27` | botao `OK/SELECT` | `config.h` + `ui_init.cpp` | `INPUT_PULLUP`; chave para `GND` | confirmado no codigo |
| `BTN_PROTOCOL` | `GPIO18` | botao de troca rapida de protocolo | `config.h` + `ui_init.cpp` | `INPUT_PULLUP`; chave para `GND` | confirmado no codigo |
| `ENC_A` | `GPIO14` | `KY-040 CLK` | `config.h` + `ui_init.cpp` + `docs/mapa-gpio-reva.md` | logica em `+3V3_AUX`; fora dos pinos mais sensiveis de boot | confirmado no codigo |
| `ENC_B` | `GPIO13` | `KY-040 DT` | `config.h` + `ui_init.cpp` + `wokwi/diagram.json` | logica em `+3V3_AUX` | confirmado no codigo |
| `ENC_SW` | `GPIO19` | botao do encoder | `config.h` + `ui_init.cpp` + `docs/mapa-gpio-reva.md` | `INPUT_PULLUP`; chave para `GND` | confirmado no codigo |
| `DIP_BIT0` | `GPIO34` | bit 0 do protocolo de boot | `config.h` + `main.cpp` + `docs/mapa-gpio-reva.md` | somente entrada; precisa `pull-up` externo `10k` | confirmado no codigo |
| `DIP_BIT1` | `GPIO35` | bit 1 do protocolo de boot | `config.h` + `main.cpp` + `docs/mapa-gpio-reva.md` | somente entrada; precisa `pull-up` externo `10k` | confirmado no codigo |
| `DIP_BIT2` | `GPIO36` | bit 2 do protocolo de boot | `config.h` + `main.cpp` + `docs/mapa-gpio-reva.md` | somente entrada; precisa `pull-up` externo `10k` | confirmado no codigo |
| `LED_TX` | `GPIO23` | LED externo opcional de trafego TX | `config.h` + `main.cpp` + `docs/mapa-gpio-reva.md` | usar resistor serie `330R` se montado | confirmado no codigo |
| `LED_BUILTIN` | `GPIO2` | heartbeat no LED onboard do DevKit | `config.h` + `main.cpp` | LED do modulo comercial; nao aparece como item dedicado no handoff RevA | confirmado no codigo |

## Conector OBD-II

| Sinal | GPIO / pino fisico | Funcao | Origem da confirmacao | Observacoes eletricas | Classificacao |
|---|---|---|---|---|---|
| `GND_CHASSIS` | `J1 pin 4` | retorno de terra | `docs/hardware.md` + `docs/diagrama-eletrico-pcb.md` + `netlist-rev-a.csv` | ligado ao `GND` comum da placa | confirmado na documentacao/EDA existente |
| `GND_SIGNAL` | `J1 pin 5` | retorno de terra | `docs/hardware.md` + `docs/diagrama-eletrico-pcb.md` + `netlist-rev-a.csv` | ligado ao `GND` comum da placa | confirmado na documentacao/EDA existente |
| `CANH` | `J1 pin 6` | barramento CAN high | `docs/hardware.md` + `docs/diagrama-eletrico-pcb.md` + `netlist-rev-a.csv` | vai ao `U2 CANH`; roteamento pareado com `CANL` | confirmado na documentacao/EDA existente |
| `KLINE` | `J1 pin 7` | barramento K-Line | `docs/hardware.md` + `docs/kline-l9637d-montagem.md` + `netlist-rev-a.csv` | vai ao `U3 pin 6`; idle alto em `+12V` | confirmado na documentacao/EDA existente |
| `CANL` | `J1 pin 14` | barramento CAN low | `docs/hardware.md` + `docs/diagrama-eletrico-pcb.md` + `netlist-rev-a.csv` | vai ao `U2 CANL`; roteamento pareado com `CANH` | confirmado na documentacao/EDA existente |
| `L_LINE` | `J1 pin 15` | `L-Line` | `docs/hardware.md` + `docs/kline-l9637d-montagem.md` | documentada como `NC` nesta revisao | confirmado na documentacao/EDA existente |
| `+12V_OBD` | `J1 pin 16` | alimentacao de entrada | `docs/hardware.md` + `docs/diagrama-eletrico-pcb.md` + `netlist-rev-a.csv` | fonte primaria do sistema | confirmado na documentacao/EDA existente |

## Alimentacao e rails

| Sinal | GPIO / pino fisico | Funcao | Origem da confirmacao | Observacoes eletricas | Classificacao |
|---|---|---|---|---|---|
| `+12V_OBD` | `J1 pin 16` | entrada principal automotiva | docs + handoff | deve ser protegido antes do buck e antes de distribuir para `U3 VS` | confirmado na documentacao/EDA existente |
| `+12V_PROT` | apos `F1` | rail `+12V` protegido | `docs/diagrama-eletrico-pcb.md` + `netlist-rev-a.csv` + `power_input.kicad_sch` | alimenta `U1`, `U3 VS`, `RK1` e `RLI1` | confirmado na documentacao/EDA existente |
| `+5V_SYS` | saida do buck `U1` | alimenta `VIN/5V` do DevKit | `docs/diagrama-eletrico-pcb.md` + `netlist-rev-a.csv` | depende de `LM2596` ou buck equivalente | confirmado na documentacao/EDA existente |
| `+3V3_AUX` | saida do regulador `3.3V` dedicado | logica dos perifericos | `docs/diagrama-eletrico-pcb.md` + `netlist-rev-a.csv` + `docs/mapa-gpio-reva.md` | rail de `U2`, `U3 VCC`, `OLED`, encoder e pull-ups do DIP; nao interligar ao `3V3` do DevKit | confirmado na documentacao/EDA existente |
| `GND` | `J1 pin 4/5`, `U1`, `MCU1`, `U2`, `U3`, UI | referencia comum | `docs/diagrama-eletrico-pcb.md` + `netlist-rev-a.csv` | manter plano continuo e retorno curto | confirmado na documentacao/EDA existente |

## Transceivers e sinais externos

| Sinal | GPIO / pino fisico | Funcao | Origem da confirmacao | Observacoes eletricas | Classificacao |
|---|---|---|---|---|---|
| `U2 TXD` | `SN65HVD230 pin 1` | entrada de TX do transceiver CAN | `docs/diagrama-eletrico-pcb.md` + `netlist-rev-a.csv` | ligado a `GPIO4` | confirmado na documentacao/EDA existente |
| `U2 RXD` | `SN65HVD230 pin 4` | saida de RX do transceiver CAN | `docs/diagrama-eletrico-pcb.md` + `netlist-rev-a.csv` | ligado a `GPIO5` | confirmado na documentacao/EDA existente |
| `U2 VCC` | `SN65HVD230 pin 3` | alimentacao `+3V3_AUX` | `docs/hardware.md` + `netlist-rev-a.csv` | transceiver CAN nativo no rail auxiliar | confirmado na documentacao/EDA existente |
| `U2 RS` | `SN65HVD230 pin 8` | configuracao de slope/mode | `docs/hardware.md` + `netlist-rev-a.csv` | amarrado a `GND` para modo rapido | confirmado na documentacao/EDA existente |
| `U3 RX` | `L9637D pin 1` | retorno K-Line para o ESP32 | `docs/kline-l9637d-montagem.md` + `netlist-rev-a.csv` | ligado a `GPIO16` | confirmado na documentacao/EDA existente |
| `U3 TX` | `L9637D pin 4` | comando K-Line vindo do ESP32 | `docs/kline-l9637d-montagem.md` + `netlist-rev-a.csv` | ligado a `GPIO17` | confirmado na documentacao/EDA existente |
| `U3 VCC` | `L9637D pin 3` | logica `+3V3_AUX` | `docs/kline-l9637d-montagem.md` + `netlist-rev-a.csv` | desacoplado por `CK1` | confirmado na documentacao/EDA existente |
| `U3 VS` | `L9637D pin 7` | dominio automotivo `+12V` | `docs/kline-l9637d-montagem.md` + `netlist-rev-a.csv` | desacoplado por `CK2` | confirmado na documentacao/EDA existente |
| `U3 K` | `L9637D pin 6` | barramento K-Line externo | `docs/kline-l9637d-montagem.md` + `netlist-rev-a.csv` | puxado para `VS` por `RK1 510R` | confirmado na documentacao/EDA existente |
| `U3 LI` | `L9637D pin 8` | bias de linha | `docs/kline-l9637d-montagem.md` + `netlist-rev-a.csv` | ligado a `VS` via `RLI1 10k` | confirmado na documentacao/EDA existente |
| `U3 LO` | `L9637D pin 2` | saida nao usada | `docs/kline-l9637d-montagem.md` | `NC` nesta revisao | confirmado na documentacao/EDA existente |

## Programacao e debug

| Sinal | GPIO / pino fisico | Funcao | Origem da confirmacao | Observacoes eletricas | Classificacao |
|---|---|---|---|---|---|
| `USB_DEVKIT` | conector USB do modulo | gravacao do firmware e serial monitor | `docs/reva-carrier-esp32-devkit.md` + `README.md` | precisa ficar acessivel na borda da carrier | confirmado na documentacao/EDA existente |
| `UART0 debug` | serial do DevKit | `Serial.begin(115200)` no boot | `main.cpp` | depende do modulo comercial e da interface USB serial do DevKit | confirmado no codigo |

## Restricoes relevantes do ESP32

| Item | Observacao | Origem |
|---|---|---|
| `GPIO34-39` | somente entrada, sem `pull-up` interno | comportamento do ESP32 refletido em `docs/mapa-gpio-reva.md` e no uso real do firmware |
| `GPIO12` | pino sensivel de boot; fora da UI final | registrado em `docs/mapa-gpio-reva.md` |
| `GPIO15` | pino sensivel de boot; fora da UI final | registrado em `docs/mapa-gpio-reva.md` |
| `GPIO6-11` | reservados para flash interna | registrados no mapeamento do DevKit; nao usados no projeto |
| `GPIO1/GPIO3` | associados ao caminho USB/serial do DevKit | documentacao historica + uso de `Serial` no firmware |

## Conflitos e observacoes de engenharia

1. A definicao de comportamento da UI local fica no firmware atual, especialmente em `ui_init.cpp`.
   - para pinagem e comportamento real, priorizar `ui_init.cpp`

2. O pinout do carrier RevA depende do `ESP32 DevKit` comercial exato.
   - o mapeamento de GPIO esta congelado
   - a geometria final dos headers ainda depende da escolha do modulo

3. `L-Line` permanece `NC` nesta consolidacao.
   - se uma revisao futura exigir `L-Line`, isso sera mudanca de hardware e de documentacao, nao desta rodada

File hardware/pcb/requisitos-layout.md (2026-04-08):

# Requisitos de Layout da PCB

Documento orientado a layout para a `RevA` do `YouSimuladorOBD`.

## Objetivo

Guiar o layout de uma placa:

- fiel a bancada validada
- robusta para ambiente automotivo/OBD
- de baixo risco para a primeira fabricacao

## Escopo da RevA

- `carrier` para `ESP32 DevKit 38 pinos`
- `SN65HVD230` para CAN
- `L9637D` para K-Line
- `OLED SH1107` via header
- `KY-040` via header
- buck `12V -> 5V` baseado em `LM2596` ou equivalente

## 1. Protecao contra surto

- colocar `TVS` diretamente na entrada `+12V` vinda de `J1 pin 16`
- colocar a `TVS` fisicamente antes da distribuicao para buck e `L9637D VS`
- manter o retorno da `TVS` ao `GND` com caminho curto e de baixa impedancia
- evitar que o surto passe pela placa inteira antes de encontrar o clamp
- usar `SMCJ24A` como referencia pratica de `TVS1` para a RevA

Status:

- recomendado por engenharia
- nao confirmado como item fechado de bancada

## 2. ESD

- prever protecao ESD nas linhas externas acessiveis do OBD, principalmente `CANH`, `CANL` e `K`
- colocar a protecao o mais perto possivel do conector externo
- manter caminho curto entre o dispositivo de protecao e o plano de `GND`
- usar `PESD2CAN24LT-Q` como referencia para `CANH/CANL`
- usar `ESDLIN1524BJ` como referencia para `K-Line`

Status:

- inferido / hipotese fortemente recomendada

## 3. Inversao de polaridade

- incluir protecao de polaridade reversa na entrada `+12V`
- preferir topologia com baixa perda se o envelope termico permitir
- usar `LM74502-Q1` com MOSFETs externos como referencia principal de baixo risco/perda para a PCB final
- o fechamento dos MOSFETs ainda depende da corrente alvo e da dissipacao

Status:

- recomendado por engenharia
- topologia final ainda em aberto

## 4. Ruido e dominios de alimentacao

Separar claramente no esquematico e no layout os dominios:

- `+12V_OBD`
- `+12V_PROT`
- `+5V_SYS`
- `+3V3_AUX`
- `GND`

Regras:

- manter `+12V_PROT` longe da regiao de antena do ESP32
- manter o buck e suas correntes pulsantes longe de `CAN`, `K-Line`, `I2C` e da antena
- manter o regulador de `+3V3_AUX` e seu desacoplamento perto dos perifericos mais sensiveis
- nao interligar `+3V3_AUX` com o `3V3` de saida do `ESP32 DevKit`
- usar plano de `GND` continuo, com poucos estrangulamentos
- evitar rotas longas de retorno para os desacoplamentos

## 5. Posicionamento do fusivel, TVS e buck

- `F1` deve ficar na entrada da placa, logo apos `J1 pin 16`
- `TVS1` deve ficar entre `+12V_PROT` e `GND`, o mais proximo da entrada
- `U1` buck deve ficar na zona de potencia, antes da area de logica
- manter a malha quente do buck minima
- nao colocar o buck sob a antena do `ESP32 DevKit`

## 6. Keepout da antena do ESP32 DevKit

Obrigatorio para a RevA:

- sem cobre sob a antena
- sem trilhas de alta comutacao sob a antena
- sem transceiver, buck, TVS ou componentes altos encostados na antena

Referencia base:

- `docs/reva-carrier-esp32-devkit.md`

## 7. Posicionamento de `SN65HVD230` e `L9637D`

### `U2 SN65HVD230`

- colocar perto do conector OBD
- manter `CANH` e `CANL` curtos ate `J1`
- colocar `CCAN1` junto ao `VCC/GND` do CI
- manter `RS` curto ate `GND`

### `U3 L9637D`

- colocar perto do conector OBD
- manter `K` curto ate `J1 pin 7`
- manter `VS` curto e robusto ate `+12V_PROT`
- colocar `CK1` e `CK2` encostados no CI
- dar area termica e ventilacao minima para `RK1 510R`

## 8. Roteamento CANH/CANL

- rotear `CANH` e `CANL` como par, lado a lado
- manter comprimento semelhante e poucas mudancas bruscas
- evitar stubs desnecessarios
- deixar `RCAN1` proximo da saida do barramento ou em posicao que faca sentido para populacao opcional
- manter afastamento razoavel do buck e de trilhas ruidosas

## 9. Roteamento da K-Line

- manter `KLINE` curta, direta e protegida
- separar `KLINE` do laco de comutacao do buck
- manter `TX_K` e `RX_K` logicos longe da regiao de potencia
- minimizar a area de loop entre `U3`, `RK1`, `RLI1`, `CK2` e o conector OBD

## 10. Desacoplamento

- todo CI deve ter desacoplamento local
- `CK1` e `CK2` sao obrigatorios para o `L9637D`
- `CCAN1` deve ficar junto do `SN65HVD230`
- o `ESP32 DevKit` ja traz parte do desacoplamento no proprio modulo, mas a carrier nao deve degradar esse ambiente com retorno ruim

## 11. Retorno de corrente e GND

- usar plano de `GND` continuo sempre que possivel
- evitar recortes que forcem retorno longo entre transceivers e o conector OBD
- conectar `J1 pin 4` e `J1 pin 5` ao `GND` comum com baixa impedancia
- tratar o encontro entre correntes do buck e logica de forma cuidadosa para nao injetar ruido nos barramentos

## 12. Pontos de teste minimos

Minimos recomendados:

- `TP_+12V`
- `TP_+5V`
- `TP_+3V3_AUX`
- `TP_GND`
- `TP_CANH`
- `TP_CANL`
- `TP_K`
- `TP_TX_K`
- `TP_RX_K`

Se houver espaco:

- `TP_VS_U3`
- `TP_TWDIAG` ou referencia equivalente de debug local

## 13. Regras de painel e conectividade local

- alinhar `OLED`, `encoder` e botoes com a mecanica prevista em `hardware/cad/`
- confirmar o modulo real do `OLED` e do `KY-040` antes de congelar os furos e headers
- manter a leitura visual dos LEDs e o acesso ao `USB` do DevKit

## 14. Recomendacoes especificas para a RevA

- preservar a arquitetura de baixo risco validada em bancada
- nao integrar `ESP32-WROOM` nesta revisao
- manter a fonte dedicada de `+3V3_AUX` para os perifericos, sem interligacao com o `3V3` do DevKit
- preferir populacao opcional para itens ainda em avaliacao, como `RCAN1`

## 15. Evolucao futura

Para uma revisao posterior, considerar:

- `ESP32-WROOM` integrado
- protecao automotiva mais completa e fechada por componente
- conector OBD e filtragem EMC fechados com requisitos de produto
- eventual integracao de medicao de tensao/corrente

## 16. Pendencias que devem ser resolvidas antes do layout final

- part number exato do `ESP32 DevKit`
- modulo final do `OLED`
- modulo final do `KY-040`
- validacao final da `SMCJ24A` no ambiente real do produto
- escolha final dos MOSFETs do `LM74502-Q1`
- forma final do conector OBD
- corrente alvo do buck se deixar de ser modulo pronto

## 17. Componentes de protecao sugeridos para compra/prototipo de PCB

- `F1`: fusivel `1A`
- `TVS1`: `SMCJ24A` unidirecional
- `D_ESD_CAN1`: `PESD2CAN24LT-Q`
- `D_ESD_K1`: `ESDLIN1524BJ`
- `UREV1`: `LM74502-Q1`
- `QREV1/QREV2`: `2 x MOSFET N` externos, a fechar pela corrente alvo

Esses itens sao recomendacoes de engenharia para a `RevA` e devem ser tratados como baseline proposto, nao como itens confirmados pelo firmware.

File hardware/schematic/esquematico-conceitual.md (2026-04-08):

# Esquematico Conceitual da RevA

Documento textual por blocos para orientar a captura do esquematico real da `RevA`.

Fontes base:

- `docs/hardware.md`
- `docs/pinout.md`
- `docs/diagrama-eletrico-pcb.md`
- `hardware/pcb-handoff/netlist-rev-a.csv`
- `hardware/pcb-handoff/bom-rev-a.csv`
- `hardware/kicad/revA/*.kicad_sch`

Legenda de confianca:

- `confirmado no codigo`
- `confirmado na documentacao/EDA existente`
- `inferido / hipotese`

## 1. Alimentacao e protecao de entrada

### Componentes envolvidos

- `J1` conector OBD-II
- `F1` fusivel de entrada
- `TVS1` opcional/recomendada para PCB final
- elemento de protecao contra inversao de polaridade a definir

### Ligacoes principais

```text
J1 pin 16 -> F1 -> +12V_PROT
J1 pin 4  -> GND
J1 pin 5  -> GND
```

### Observacoes de projeto

- a placa deve nascer do `+12V` do OBD, nao de `USB`
- `J1 pin 16` tambem precisa alimentar o `VS` do `L9637D`
- a protecao automotiva precisa ficar na boca da placa, antes do buck e antes da distribuicao do `+12V`

### Cuidados de layout

- posicionar fusivel e TVS o mais perto possivel do conector OBD
- manter o loop de entrada `J1 -> F1 -> TVS/buck -> GND` curto
- prever trilhas e cobre compativeis com o pico de corrente de partida do buck

### Nivel de confianca

- `J1` e `F1`: confirmado na documentacao/EDA existente
- `TVS1` e protecao contra inversao: inferido / hipotese fortemente recomendada

## 2. Reguladores

### Componentes envolvidos

- `U1` buck `12V -> 5V`, baseline `LM2596`
- `U4` regulador `3.3V` dedicado para perifericos

### Ligacoes principais

```text
+12V_PROT -> U1 IN+
GND       -> U1 IN-
U1 OUT+   -> +5V_SYS -> MCU1 VIN
U1 OUT-   -> GND
+5V_SYS   -> U4 IN
U4 OUT    -> +3V3_AUX
```

### Observacoes de projeto

- a `RevA` foi congelada para aceitar `LM2596` modulo ou equivalente de baixo risco
- a carrier usa `+3V3_AUX` dedicado para alimentar `SN65HVD230`, `L9637D VCC`, `OLED`, `encoder` e `pull-ups` do DIP
- `+3V3_AUX` nao deve ser interligado ao pino `3V3` de saida do DevKit

### Cuidados de layout

- isolar a regiao do buck da regiao da antena do ESP32
- reservar area termica para o buck e para o resistor `RK1`
- manter retorno de corrente do buck curto e com plano de GND consistente

### Nivel de confianca

- topologia `12V -> 5V -> VIN do DevKit`: confirmado na documentacao/EDA existente
- corrente maxima e implementacao final do buck: inferido / hipotese ate fechar o componente final

## 3. MCU

### Componentes envolvidos

- `MCU1` `ESP32 DevKit 38 pinos`
- `JMCU1`, `JMCU2` headers femea `1x19`

### Ligacoes principais

```text
+5V_SYS -> MCU1 VIN
GND     -> MCU1 GND
GPIO4/5  -> CAN
GPIO17/16 -> K-Line
GPIO21/22 -> OLED
GPIO32/33/25/26/27/18 -> botoes
GPIO14/13/19 -> encoder
GPIO34/35/36 -> DIP
GPIO23 -> LED_TX opcional
GPIO2 -> LED onboard do DevKit
```

### Observacoes de projeto

- a `RevA` e carrier, nao placa integrada do modulo ESP32
- o USB do DevKit precisa ficar acessivel na borda do conjunto
- o LED onboard em `GPIO2` existe no modulo comercial, nao precisa necessariamente de item dedicado na carrier

### Cuidados de layout

- respeitar keepout de antena sem cobre e sem componentes
- confirmar o DevKit comercial exato antes de travar footprints
- manter acesso mecanico ao USB e espaco para cabo

### Nivel de confianca

- pinagem funcional: confirmado no codigo
- geometria final do modulo comercial: inferido / hipotese ate confirmar o part number

## 4. Interface OBD

### Componentes envolvidos

- `J1` conector OBD-II

### Ligacoes principais

```text
J1 pin 4  -> GND
J1 pin 5  -> GND
J1 pin 6  -> CANH
J1 pin 7  -> KLINE
J1 pin 14 -> CANL
J1 pin 15 -> NC
J1 pin 16 -> +12V_OBD
```

### Observacoes de projeto

- nesta revisao `L-Line` permanece `NC`
- o conector final pode ser de placa ou chicote, mas a pinagem logica do projeto nao muda

### Cuidados de layout

- deixar acesso facil a pontos de teste de `CANH`, `CANL`, `KLINE`, `+12V` e `GND`
- proteger as linhas externas ja na entrada

### Nivel de confianca

- mapeamento funcional dos pinos usados: confirmado na documentacao/EDA existente

## 5. Interface CAN

### Componentes envolvidos

- `U2` `SN65HVD230`
- `CCAN1` `100nF`
- `RCAN1` `120R` opcional/jumper

### Ligacoes principais

```text
GPIO4         -> U2 TXD
GPIO5         <- U2 RXD
+3V3_AUX      -> U2 VCC
GND           -> U2 GND
GND           -> U2 RS
U2 CANH       -> J1 pin 6
U2 CANL       -> J1 pin 14
RCAN1 120R    -> entre CANH e CANL (opcional/jumper)
CCAN1 100nF   -> entre U2 VCC e GND
```

### Observacoes de projeto

- o firmware usa o `TWAI` nativo do ESP32; nao existe controlador CAN externo no projeto
- a terminacao CAN precisa ser explicitada na PCB mesmo que algum breakout de bancada ja a tivesse

### Cuidados de layout

- manter `CANH` e `CANL` paralelos, curtos e com impedancia o mais controlada possivel dentro da realidade da placa
- colocar `U2` perto do conector OBD
- colocar `CCAN1` colado no CI

### Nivel de confianca

- uso de CAN e pinagem logica: confirmado no codigo
- transceiver, terminacao e desacoplamento: confirmado na documentacao/EDA existente

## 6. Interface K-Line

### Componentes envolvidos

- `U3` `L9637D`
- `RK1` `510R`
- `RLI1` `10k`
- `CK1` `100nF`
- `CK2` `100nF`

### Ligacoes principais

```text
GPIO17      -> U3 pin 4 (TX)
GPIO16      <- U3 pin 1 (RX)
+3V3_AUX    -> U3 pin 3 (VCC)
GND         -> U3 pin 5 (GND)
KLINE       -> U3 pin 6 (K) -> J1 pin 7
+12V_PROT   -> U3 pin 7 (VS)
RLI1 10k    -> U3 pin 8 (LI) para U3 pin 7 (VS)
RK1 510R    -> U3 pin 6 (K) para U3 pin 7 (VS)
CK1 100nF   -> U3 pin 3 para GND
CK2 100nF   -> U3 pin 7 para GND
U3 pin 2    -> NC
```

### Observacoes de projeto

- este e o bloco mais sensivel do projeto porque a bancada validada depende explicitamente de `RK1`, `RLI1`, `CK1` e `CK2`
- o firmware suporta `ISO 9141-2`, `KWP 5-baud` e `KWP Fast`
- a placa precisa preservar o comportamento de idle alto da linha `K`

### Cuidados de layout

- colocar `U3` perto do conector OBD
- colocar `CK1` e `CK2` encostados no CI
- dar folga termica a `RK1`
- deixar pontos de teste em `K`, `TX_K`, `RX_K`, `VS` e `GND`

### Nivel de confianca

- pinagem logica, UART1 e comportamento de protocolo: confirmado no codigo
- topologia eletrica do frontend K-Line: confirmado na documentacao/EDA existente

## 7. Programacao e debug

### Componentes envolvidos

- conector `USB` do `ESP32 DevKit`
- `Serial` do modulo

### Ligacoes principais

```text
USB do DevKit -> gravacao de firmware
USB do DevKit -> monitor serial em 115200
```

### Observacoes de projeto

- a carrier deve prever acesso mecanico ao USB
- nesta revisao nao e necessario adicionar interface extra de programacao se o DevKit mantiver USB acessivel

### Cuidados de layout

- preservar janela mecanica para o cabo
- nao bloquear o DevKit com componentes altos ao redor do conector USB

### Nivel de confianca

- `Serial.begin(115200)` confirmado no codigo
- uso do USB do DevKit como caminho fisico: confirmado na documentacao/EDA existente

## 8. LEDs

### Componentes envolvidos

- `D3`
- `RLED3`

### Ligacoes principais

```text
GPIO23 -> RLED3 -> D3 -> GND
GPIO2  -> LED onboard do DevKit
```

### Observacoes de projeto

- apenas o `LED_TX` externo permanece como opcional na carrier
- o LED onboard depende do modulo comercial do DevKit

### Cuidados de layout

- manter polaridade clara na serigrafia
- posicionar de forma visivel ao usuario quando o conjunto estiver fechado

### Nivel de confianca

- GPIOs dos LEDs: confirmado no codigo
- resistores serie e LEDs externos: confirmado na documentacao/EDA existente

## 9. Botoes

### Componentes envolvidos

- `SW2-SW7`

### Ligacoes principais

```text
GPIO32 -> SW2 -> GND
GPIO33 -> SW3 -> GND
GPIO25 -> SW4 -> GND
GPIO26 -> SW5 -> GND
GPIO27 -> SW6 -> GND
GPIO18 -> SW7 -> GND
```

### Observacoes de projeto

- os botoes usam `INPUT_PULLUP`; nao precisam de `pull-up` externo

### Cuidados de layout

- roteamento simples, curto e com referencia de GND
- manter acessibilidade mecanica coerente com a tampa frontal

### Nivel de confianca

- confirmado no codigo + confirmado na documentacao/EDA existente

## 10. Encoder

### Componentes envolvidos

- `ENC1` `KY-040`
- `JENC1`

### Ligacoes principais

```text
GPIO14 -> ENC1 CLK
GPIO13 -> ENC1 DT
GPIO19 -> ENC1 SW
+3V3_AUX -> ENC1 +
GND -> ENC1 GND
```

### Observacoes de projeto

- o firmware usa `ESP32Encoder`
- o `KY-040` e tratado como modulo/placa filha nesta RevA
- `GPIO12` e `GPIO15` ficam fora da UI final para evitar risco de boot

### Cuidados de layout

- respeitar a mecanica do painel frontal
- manter o modulo do encoder alimentado por `+3V3_AUX`

### Nivel de confianca

- pinagem funcional: confirmado no codigo
- header/modulo na RevA: confirmado na documentacao/EDA existente

## 11. DIP

### Componentes envolvidos

- `SW1`
- `RDIP1-RDIP3`

### Ligacoes principais

```text
+3V3_AUX -> RDIP1 -> GPIO34 -> SW1 bit 0 -> GND
+3V3_AUX -> RDIP2 -> GPIO35 -> SW1 bit 1 -> GND
+3V3_AUX -> RDIP3 -> GPIO36 -> SW1 bit 2 -> GND
```

### Observacoes de projeto

- leitura no boot via `main.cpp`
- chave fechada para `GND` representa `LOW`

### Cuidados de layout

- manter trilhas simples e longe de fontes de ruido desnecessarias
- deixar orientacao do DIP clara na serigrafia

### Nivel de confianca

- confirmado no codigo + confirmado na documentacao/EDA existente

## 12. Conectores

### Componentes envolvidos

- `J1` OBD-II
- `JMCU1/JMCU2`
- `JDISP1`
- `JENC1`

### Observacoes de projeto

- a carrier precisa acomodar o DevKit, o OLED e o encoder de forma coerente com a mecanica da case
- `MH1-MH4` devem ser mantidos como furos de fixacao da placa

### Nivel de confianca

- confirmado na documentacao/EDA existente

## 13. Pontos de teste

### Pontos minimos recomendados

- `TP_+12V`
- `TP_+5V`
- `TP_+3V3_AUX`
- `TP_GND`
- `TP_CANH`
- `TP_CANL`
- `TP_K`
- `TP_TX_K`
- `TP_RX_K`

### Observacoes de projeto

- esses pontos aparecem de forma recorrente como necessidade pratica de bancada
- nao estao todos congelados como RefDes no handoff atual, mas devem entrar na PCB final

### Nivel de confianca

- necessidade funcional: confirmado na documentacao/EDA existente
- RefDes e geometria final: inferido / hipotese

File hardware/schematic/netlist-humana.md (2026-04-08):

# Netlist Humana

Fonte primaria:

- `hardware/pcb-handoff/netlist-rev-a.csv`

Fontes de cruzamento:

- `docs/hardware.md`
- `docs/pinout.md`
- `firmware/include/config.h`
- `docs/kline-l9637d-montagem.md`
- `docs/diagrama-eletrico-pcb.md`

Legenda curta:

- `[CC]` confirmado no codigo
- `[DE]` confirmado na documentacao/EDA existente
- `[IH]` inferido / hipotese

- `+12V_OBD -> J1-16` `[DE]`
- `+12V_PROT -> F1-2, U1-IN+, U3-7(VS), RK1-1, RLI1-1` `[DE]`
- `GND -> J1-4, J1-5, U1-IN-, U1-OUT-, MCU1-GND, U2-2(GND), U2-8(RS), U3-5(GND), CK1-2, CK2-2, DISP1-GND, ENC1-GND, SW2-SW7-retorno, SW1-comum, D3-catodo` `[DE]`
- `+5V_SYS -> U1-OUT+, MCU1-VIN` `[DE]`
- `+5V_SYS -> U4-IN` `[DE]`
- `+3V3_AUX -> U4-OUT, U2-3(VCC), U3-3(VCC), DISP1-VCC, ENC1-VCC, RDIP1-1, RDIP2-1, RDIP3-1` `[DE]`
- `CAN_TX_LOGIC -> MCU1-GPIO4, U2-1(TXD)` `[CC/DE]`
- `CAN_RX_LOGIC -> U2-4(RXD), MCU1-GPIO5` `[CC/DE]`
- `CANH -> U2-7(CANH), J1-6` `[DE]`
- `CANL -> U2-6(CANL), J1-14` `[DE]`
- `CAN_TERM_OPTIONAL -> RCAN1-1 entre CANH, RCAN1-2 entre CANL` `[DE]`
- `K_TX_LOGIC -> MCU1-GPIO17, U3-4(TX)` `[CC/DE]`
- `K_RX_LOGIC -> U3-1(RX), MCU1-GPIO16` `[CC/DE]`
- `KLINE -> U3-6(K), J1-7, RK1-2` `[DE]`
- `LI_BIAS -> U3-8(LI), RLI1-2` `[DE]`
- `CK1_VCC -> U3-3(VCC), CK1-1` `[DE]`
- `CK2_VS -> U3-7(VS), CK2-1` `[DE]`
- `I2C_SDA -> MCU1-GPIO21, DISP1-SDA` `[CC/DE]`
- `I2C_SCL -> MCU1-GPIO22, DISP1-SCL` `[CC/DE]`
- `ENC_A -> MCU1-GPIO14, ENC1-CLK` `[CC/DE]`
- `ENC_B -> MCU1-GPIO13, ENC1-DT` `[CC/DE]`
- `ENC_SW -> MCU1-GPIO19, ENC1-SW` `[CC/DE]`
- `BTN_PREV -> MCU1-GPIO32, SW2` `[CC/DE]`
- `BTN_NEXT -> MCU1-GPIO33, SW3` `[CC/DE]`
- `BTN_UP -> MCU1-GPIO25, SW4` `[CC/DE]`
- `BTN_DOWN -> MCU1-GPIO26, SW5` `[CC/DE]`
- `BTN_SELECT -> MCU1-GPIO27, SW6` `[CC/DE]`
- `BTN_PROTOCOL -> MCU1-GPIO18, SW7` `[CC/DE]`
- `DIP_BIT0 -> MCU1-GPIO34, RDIP1-2, SW1-bit0` `[CC/DE]`
- `DIP_BIT1 -> MCU1-GPIO35, RDIP2-2, SW1-bit1` `[CC/DE]`
- `DIP_BIT2 -> MCU1-GPIO36, RDIP3-2, SW1-bit2` `[CC/DE]`
- `LED_TX -> MCU1-GPIO23, RLED3-1` `[CC/DE]`
- `LED_BUILTIN_ONBOARD -> MCU1-GPIO2, LED onboard do DevKit` `[CC/IH]`
- `USB_DEVKIT -> conector USB do modulo MCU1, UART0/gravacao` `[DE]`

## Notas de leitura

- A maior parte das nets de carrier vem do handoff CSV e da documentacao de `RevA`.
- As nets `CAN_*`, `K_*`, `I2C_*`, `BTN_*`, `ENC_*`, `DIP_*` e `LED_*` tambem estao confirmadas diretamente pelo firmware.
- `LED_BUILTIN_ONBOARD` nao aparece no handoff de PCB porque pertence ao modulo comercial do DevKit.

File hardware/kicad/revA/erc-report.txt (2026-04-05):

ERC report (2026-04-05T01:53:31, Encoding UTF8)
Report includes: Warnings

***** Sheet /

***** Sheet /Power_Input/

***** Sheet /UI_Local/

***** Sheet /ESP32_Core/

***** Sheet /OBD_Transceivers/

 ** ERC messages: 0  Errors 0  Warnings 0

 ** Ignored checks:
    - Global label only appears once in the schematic
    - Four connection points are joined together
    - SPICE model issue
    - Assigned footprint doesn't match footprint filters

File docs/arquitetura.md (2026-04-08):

# Arquitetura Canonica do Firmware

Documento canonico de arquitetura embarcada do `YouSimuladorOBD`.

Objetivo:

- explicar como o firmware conversa com o hardware real
- apontar os modulos principais e suas responsabilidades
- separar a arquitetura atual de descricoes historicas mais antigas

## Visao geral

O firmware roda sobre `Arduino-ESP32` com `FreeRTOS` e foi organizado para manter quatro frentes em paralelo:

- barramentos OBD (`CAN` e `K-Line`)
- simulacao e estado do veiculo
- interface local (`OLED`, botoes, encoder, LEDs)
- interface de rede (`Wi-Fi`, `Web UI`, `API`, `WebSocket`, `OTA`)

O ponto central da arquitetura e a estrutura `SimulationState`, compartilhada entre os workers com sincronizacao por `SemaphoreHandle_t`.

## Stack e dependencias

| Camada | Escolha atual |
|---|---|
| MCU | `ESP32 DevKit 38 pinos` |
| Framework | `Arduino` sobre `FreeRTOS` |
| Build | `PlatformIO` |
| Filesystem | `LittleFS` |
| Persistencia | `Preferences / NVS` |
| CAN | `TWAI` nativo do ESP32 |
| K-Line | `UART1` + GPIO |
| UI local | `Adafruit SH110X`, `Adafruit GFX`, `ESP32Encoder`, `Bounce2` |
| Web | `ESPAsyncWebServer-esphome`, `ArduinoJson` |

## Fluxo principal entre hardware e software

```text
Scanner OBD
  -> J1 OBD-II
  -> SN65HVD230 ou L9637D
  -> ESP32 (TWAI ou UART1)
  -> dispatcher OBD
  -> handlers de modo
  -> SimulationState
  -> resposta ao barramento

SimulationState
  <-> UI local
  <-> Web UI / API / WebSocket
  <-> dynamic_engine
  <-> diagnostic_scenario_engine
```

## Web UI e robustez operacional

Arquivos principais:

- `firmware/data/index.html`
- `firmware/data/ota.html`
- `firmware/src/web/web_server.cpp`

Comportamento atual:

- a `Web UI` tenta operar em tempo real via `WebSocket`
- quando o `WebSocket` cai, a interface passa a usar `HTTP` como fallback
- o fallback cobre:
  - leitura de status
  - leitura de diagnostico
  - carga de cenarios
  - troca de protocolo
  - troca de modo
  - aplicacao de presets
  - aplicacao e limpeza de cenarios
  - envio de sliders e parametros manuais

Objetivo pratico:

- evitar que a tela fique "meio viva" quando o navegador perde o `WebSocket`
- manter a bancada utilizavel mesmo com reconexao em andamento
- reduzir casos em que o usuario clica em `Modo de Simulacao` ou `Camada Diagnostica` e nada acontece

Observacao importante:

- se a lista de cenarios vier vazia em uma tentativa inicial, a UI faz nova tentativa automatica
- a API continua protegida por autenticacao; o navegador reaproveita a autenticacao da sessao aberta na mesma origem

Risco operacional de laboratorio:

- a API continua protegida, mas agora Web/OTA e API usam uma credencial fixa unica definida em `firmware/include/config.h`
- hostname e manifest OTA podem mudar por NVS, porem login e senha nao divergem mais entre firmware, UI e automacao
- para validar por automacao, primeiro confirmar a autenticacao viva na Web UI e depois usar `GET /api/status`, `GET /api/diagnostics` e `GET /api/scenarios` como fonte de verdade

## Boot e orquestracao

Arquivo principal:

- `firmware/src/main.cpp`

Responsabilidades:

- iniciar `Serial`
- criar mutex global do estado
- ler o `DIP` no boot
- restaurar protocolo salvo em `NVS`
- restaurar perfil salvo em `NVS`
- configurar LEDs
- subir:
  - `protocol_init()`
  - `ui_init()`
  - `web_init()`
  - `dynamic_init()`

## Mapa de hardware visto pelo firmware

Arquivo base:

- `firmware/include/config.h`

Esse arquivo e a principal fonte de verdade para:

- GPIOs de `CAN`
- GPIOs de `K-Line`
- `I2C` do OLED
- botoes
- encoder
- DIP
- LEDs
- constantes de rede e OTA

Regra pratica:

- se a pinagem mudar um dia, este arquivo muda primeiro
- a documentacao canonica que precisa acompanhar essa mudanca e `docs/hardware.md` e `docs/pinout.md`

## Transporte OBD

Arquivos:

- `firmware/src/protocols/protocol_init.cpp`
- `firmware/src/protocols/can_protocol.cpp`
- `firmware/src/protocols/kline_protocol.cpp`

### `protocol_init.cpp`

- sobe os workers de `CAN` e `K-Line`
- ambos ficam residentes e ativam/desativam o proprio hardware de acordo com `active_protocol`

### `can_protocol.cpp`

- usa `TWAI` nativo do ESP32
- aplica configuracao de `250 kbit/s` ou `500 kbit/s`
- trata `11-bit` e `29-bit`
- recebe requests OBD
- monta resposta `ISO-TP` quando necessario
- pulsa `LED_TX` quando o diagnostico visual externo estiver populado

### `kline_protocol.cpp`

- usa `UART1`
- suporta `ISO 9141-2`, `KWP 5-baud` e `KWP Fast`
- executa o handshake de `5-baud init` e `fast init`
- monta e valida frames com checksum
- controla o idle e a sessao do barramento
- pulsa `LED_TX`

## Core OBD

Arquivos:

- `firmware/src/obd/obd_dispatcher.cpp`
- `firmware/src/obd/mode01_handler.cpp`
- `firmware/src/obd/mode02_handler.cpp`
- `firmware/src/obd/mode03_handler.cpp`
- `firmware/src/obd/mode06_handler.cpp`
- `firmware/src/obd/mode09_handler.cpp`

Responsabilidades:

- receber um `OBDRequest`
- despachar por modo
- montar um `OBDResponse`
- retornar resposta positiva ou negativa

## Estado compartilhado e simulacao

Arquivos:

- `firmware/include/simulation_state.h`
- `firmware/src/simulation/dynamic_engine.cpp`
- `firmware/src/simulation/diagnostic_scenario_engine.cpp`
- `firmware/src/simulation/alert_engine.cpp`
- `firmware/src/simulation/fault_catalog.cpp`

Responsabilidades:

- manter dados do "veiculo" simulado
- atualizar dinamica de RPM, velocidade, temperaturas, carga e combustivel
- gerenciar DTCs e cenarios
- persistir elementos de estado como protocolo e odometro

## UI local

Arquivo:

- `firmware/src/web/ui_init.cpp`

Responsabilidades:

- inicializar `Wire` e o `OLED SH1107`
- ler os `6 botoes`
- ler o `encoder`
- permitir navegacao local e troca rapida de protocolo
- refletir o `SimulationState` no display

Dependencias diretas de hardware:

- `GPIO21/22` para `I2C`
- `GPIO32/33/25/26/27/18` para botoes
- `GPIO14/13/19` para encoder
- `GPIO23` para `LED_TX` opcional
- `GPIO2` para o LED onboard do DevKit

## Web, Wi-Fi e OTA

Arquivo:

- `firmware/src/web/web_server.cpp`

Responsabilidades:

- iniciar `Wi-Fi` em `AP`, `STA` ou ambos
- publicar `mDNS`
- servir UI via `LittleFS`
- expor `API REST`
- expor `WebSocket`
- persistir configuracoes de dispositivo e redes
- coordenar `OTA`

Dependencias diretas de software:

- `ESPAsyncWebServer`
- `ArduinoJson`
- `ESPmDNS`
- `LittleFS`
- `Preferences`

## Como o firmware conversa com o hardware

### CAN

- `GPIO4` e `GPIO5`
- `TWAI` ativo apenas em protocolos CAN
- exige `SN65HVD230` ou frontend equivalente em `+3V3_AUX`

### K-Line

- `GPIO17` e `GPIO16`
- `UART1`
- exige `L9637D` em `+3V3_AUX` e a rede passiva `RK1`, `RLI1`, `CK1`, `CK2`

### UI local

- display, botoes, encoder, DIP e LEDs sao tratados como hardware de apoio diretamente acoplado ao firmware

### Rede

- usa somente a radio `Wi-Fi` do ESP32
- nao ha uso ativo de `BLE` ou `Bluetooth Classic` no firmware atual

## Conflitos documentais relevantes

1. Narrativas antigas de UI local foram removidas desta rodada; o comportamento implementado e o que esta em `ui_init.cpp`.
2. Narrativas antigas de selecao de protocolo por serial USB foram removidas; o fluxo principal atual e `NVS + DIP + UI + web`.
3. Componentes fisicos do carrier RevA nao podem ser inferidos apenas do firmware; precisam ser cruzados com `docs/diagrama-eletrico-pcb.md`, `docs/engenharia-pcb.md`, `docs/reva-carrier-esp32-devkit.md`, `hardware/pcb-handoff/` e `hardware/kicad/revA/`.

## Documentos relacionados

- [hardware.md](hardware.md)
- [pinout.md](pinout.md)
- [engenharia-pcb.md](engenharia-pcb.md)
- [06-architecture.md](06-architecture.md)

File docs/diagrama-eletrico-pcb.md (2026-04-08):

# Diagrama Eletrico e Handoff PCB

## Objetivo

Este documento e a referencia eletrica consolidada para o engenheiro capturar o esquema da placa de circuito impresso.

Importante:

- a `RevA` foi congelada como `carrier para ESP32 DevKit 38 pinos`
- o objetivo deste handoff e transformar a bancada validada em uma primeira PCB de baixo risco

Arquivos complementares:

- [hardware/pcb-handoff/README.md](../hardware/pcb-handoff/README.md)
- [hardware/pcb-handoff/netlist-rev-a.csv](../hardware/pcb-handoff/netlist-rev-a.csv)
- [hardware/pcb-handoff/bom-rev-a.csv](../hardware/pcb-handoff/bom-rev-a.csv)
- [hardware/kicad/revA/README.md](../hardware/kicad/revA/README.md)

## Diagrama eletrico funcional

```mermaid
flowchart LR
    J1["J1 OBD-II J1962"]
    F1["F1 Fuse 1A"]
    U1["U1 LM2596 module\n12V -> 5V"]
    U4["U4 3.3V regulator\n+5V -> +3V3_AUX"]
    MCU["MCU1 ESP32 DevKit 38p\npluggable on carrier RevA"]
    U2["U2 SN65HVD230"]
    U3["U3 L9637D"]
    RK1["RK1 510R >=0.5W"]
    RLI1["RLI1 10k"]
    CK1["CK1 100nF"]
    CK2["CK2 100nF"]
    RCAN1["RCAN1 120R\noptional / jumper"]
    DISP1["DISP1 OLED SH1107"]
    ENC1["ENC1 KY-040"]
    BTN["SW2-SW7 buttons"]
    DIP["SW1 DIP 3 bits\nRDIP1-RDIP3 10k -> +3V3_AUX"]
    LEDTX["D3 LED_TX optional\nRLED3 330R"]

    J1 -- "pin16 +12V" --> F1
    F1 --> U1
    F1 --> U3
    F1 --> RK1
    F1 --> RLI1

    J1 -- "pin4/pin5 GND" --> GND["GND"]
    GND --> U1
    GND --> MCU
    GND --> U2
    GND --> U3
    GND --> U4
    GND --> DISP1
    GND --> ENC1
    GND --> BTN
    GND --> LEDTX
    GND --> CK1
    GND --> CK2

    U1 -- "5V" --> MCU
    U1 -- "5V" --> U4
    U4 -- "+3V3_AUX" --> U2
    U4 -- "+3V3_AUX" --> U3
    U4 -- "+3V3_AUX" --> DISP1
    U4 -- "+3V3_AUX" --> DIP
    U4 -- "+3V3_AUX" --> ENC1

    MCU -- "GPIO4 CAN_TX" --> U2
    MCU -- "GPIO5 CAN_RX" --> U2
    U2 -- "CANH" --> J1
    U2 -- "CANL" --> J1
    RCAN1 -. "across CANH/CANL" .- U2

    MCU -- "GPIO17 K_TX" --> U3
    MCU -- "GPIO16 K_RX" --> U3
    U3 -- "K" --> J1
    RK1 --> U3
    RLI1 --> U3
    CK1 --> U3
    CK2 --> U3

    MCU -- "GPIO21 SDA / GPIO22 SCL" --> DISP1
    MCU -- "GPIO14/13/19" --> ENC1
    MCU -- "GPIO32/33/25/26/27/18" --> BTN
    MCU -- "GPIO34/35/36" --> DIP
    MCU -- "GPIO23" --> LEDTX
```

## Mapa de sinais

### Conector OBD-II

| Pino | Sinal | Destino |
|---|---|---|
| `4` | chassis GND | `GND comum` |
| `5` | signal GND | `GND comum` |
| `6` | CANH | `U2 CANH` |
| `7` | K-Line | `U3 K` |
| `14` | CANL | `U2 CANL` |
| `15` | L-Line | `NC` |
| `16` | +12V bateria | `F1`, `U1 IN+`, `U3 VS` |

### CAN

| Origem | Destino |
|---|---|
| `GPIO4` | `U2 TXD` |
| `GPIO5` | `U2 RXD` |
| `U2 CANH` | `OBD pin 6` |
| `U2 CANL` | `OBD pin 14` |

### K-Line

| Origem | Destino |
|---|---|
| `GPIO17` | `U3 pin 4 (TX)` |
| `GPIO16` | `U3 pin 1 (RX)` |
| `U3 pin 6 (K)` | `OBD pin 7` |
| `U3 pin 7 (VS)` | `+12V protegido` |
| `RK1 510R` | `U3 pin 6 -> U3 pin 7` |
| `RLI1 10k` | `U3 pin 8 -> U3 pin 7` |
| `CK1 100nF` | `U3 pin 3 -> U3 pin 5` |
| `CK2 100nF` | `U3 pin 7 -> U3 pin 5` |

## Requisitos de PCB

### Obrigatorios para reproduzir a bancada

- `U2 SN65HVD230`
- `U3 L9637D`
- `RK1 510R >= 0.5W`
- `RLI1 10k`
- `CK1 100nF`
- `CK2 100nF`
- `F1` na entrada `+12V`
- `LM2596` ou buck equivalente
- regulador `3.3V` dedicado para `+3V3_AUX`

### Recomendados para a revisao da placa

- `RCAN1 120R` configuravel por jumper ou `DNP`
- TVS na entrada `+12V`
- protecao contra inversao de polaridade
- ponto de teste em:
  - `+12V`
  - `+5V`
  - `+3V3_AUX`
  - `GND`
  - `CANH`
  - `CANL`
  - `K`
  - `K_TX_LOGIC`
  - `K_RX_LOGIC`

## Observacoes para captura do esquema

### Implementacao do MCU congelada na RevA

Para esta revisao, o MCU fica congelado como:

- `ESP32 DevKit 38 pinos`
- montado por `2 x headers femea 1x19`
- com `USB` acessivel na borda
- com keepout dedicado para a antena

Referencia:

- [RevA Carrier para ESP32 DevKit](reva-carrier-esp32-devkit.md)
- [hardware/kicad/revA/esp32-devkit38-carrier-reference.csv](../hardware/kicad/revA/esp32-devkit38-carrier-reference.csv)

### Escolha de implementacao da fonte

O hardware de bancada usa modulo `LM2596`. Para PCB:

- pode manter footprint/header para modulo buck
- ou redesenhar uma etapa buck equivalente, desde que preserve:
  - entrada `+12V`
  - saida `+5V` para `VIN`
  - corrente suficiente para `ESP32 + OLED + transceivers`

## Matriz de aceite que esta por tras deste esquema

| Barramento | Ferramenta | Resultado |
|---|---|---|
| CAN | `Torque Pro` | OK |
| CAN | `OBDLink MX+` | OK |
| ISO 9141-2 | `OBDLink app` | OK |
| ISO 9141-2 | `Torque Pro` | OK |
| ISO 9141-2 | `YouAutoCar` | OK |
| KWP Fast | `Torque Pro` | OK |

## Estado atual em EDA nativo

Ja existe um bootstrap nativo em `KiCad` em:

- `hardware/kicad/revA/YouSimuladorOBD_RevA.kicad_sch`

Esse bootstrap ainda nao e a captura completa final, mas ja organiza o projeto em folhas por bloco:

- `Power_Input`
- `ESP32_Core`
- `OBD_Transceivers`
- `UI_Local`

Assim, o engenheiro nao precisa mais partir do zero no EDA.

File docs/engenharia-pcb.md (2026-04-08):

# Guia Executivo para Engenharia de PCB

Este documento orienta o engenheiro de hardware/PCB sobre quais arquivos usar, qual e o baseline real da `RevA` e o que ainda precisa ser confirmado antes do esquematico final.

## Escopo da RevA

A `RevA` desta rodada esta congelada como:

- `carrier board para ESP32 DevKit 38 pinos`
- `SN65HVD230` para CAN
- `L9637D` para K-Line
- `OLED SH1107` via header
- `KY-040` via header
- `LM2596` ou buck equivalente de baixo risco para `12V -> 5V`

## Fase atual do projeto

O objetivo desta fase ja nao e mais validar se a arquitetura funciona em bancada. Esse marco foi atingido com o prototipo fisico atual.

Estado consolidado:

- prototipo montado e testado fisicamente
- `CAN`, `ISO 9141-2`, `KWP 5-baud` e `KWP Fast` tratados como validados
- foco imediato deslocado para `PCB RevA` e preparacao para produto

Consequencia pratica para a engenharia:

- partir do principio de que a topologia central esta aceita
- concentrar esforco em layout, protecao, repetibilidade, teste e industrializacao leve

Fora de escopo nesta rodada:

- integrar `ESP32-WROOM` diretamente na PCB
- alterar pinagem do firmware
- alterar protocolos, barramentos ou logica OBD

## Baseline real a considerar

Use como baseline combinado:

1. firmware atual
   - `firmware/include/config.h`
   - `firmware/src/main.cpp`
   - `firmware/src/protocols/*.cpp`
   - `firmware/src/web/ui_init.cpp`
   - `firmware/src/web/web_server.cpp`

2. documentacao consolidada desta rodada
   - [hardware.md](hardware.md)
   - [pinout.md](pinout.md)
   - [arquitetura.md](arquitetura.md)
   - [../hardware/schematic/esquematico-conceitual.md](../hardware/schematic/esquematico-conceitual.md)
   - [../hardware/schematic/netlist-humana.md](../hardware/schematic/netlist-humana.md)
   - [../hardware/schematic/bom-preliminar.csv](../hardware/schematic/bom-preliminar.csv)
   - [../hardware/pcb/requisitos-layout.md](../hardware/pcb/requisitos-layout.md)

3. handoff e EDA existentes
   - [../hardware/pcb-handoff/README.md](../hardware/pcb-handoff/README.md)
   - [../hardware/pcb-handoff/netlist-rev-a.csv](../hardware/pcb-handoff/netlist-rev-a.csv)
   - [../hardware/pcb-handoff/bom-rev-a.csv](../hardware/pcb-handoff/bom-rev-a.csv)
   - [../hardware/kicad/revA/README.md](../hardware/kicad/revA/README.md)
   - [../hardware/kicad/revA/YouSimuladorOBD_RevA.kicad_sch](../hardware/kicad/revA/YouSimuladorOBD_RevA.kicad_sch)

## O que esta confirmado

### Confirmado no codigo

- mapa de GPIOs do projeto
- uso de `TWAI` nativo para CAN
- uso de `UART1` para K-Line a `10400 baud`
- uso de `OLED SH1107` via `I2C`
- uso de `6 botoes`, `encoder`, `DIP` e `3 LEDs`
- uso de `Wi-Fi`, `mDNS`, `LittleFS`, `Web UI` e `OTA`

### Confirmado na documentacao/EDA existente

- `SN65HVD230` como frontend CAN
- `L9637D` como frontend K-Line
- `LM2596` como baseline de buck
- mapeamento OBD `pin 6`, `7`, `14`, `16`, `4`, `5`
- `RK1 510R`, `RLI1 10k`, `CK1 100nF`, `CK2 100nF`
- `RevA` como `carrier para ESP32 DevKit 38 pinos`
- bootstrap `KiCad RevA` dividido em blocos

## O que ainda precisa ser confirmado antes do esquematico final

- modelo comercial exato do `ESP32 DevKit 38 pinos`
- footprint final do modulo `OLED SH1107`
- footprint final do modulo `KY-040`
- validacao final da TVS de entrada `SMCJ24A` contra o ambiente real de surto do produto
- escolha final dos MOSFETs externos do `LM74502-Q1`
- estrategia final de ESD no conector OBD com `PESD2CAN24LT-Q` no CAN e `ESDLIN1524BJ` na `K-Line`
- forma final do conector OBD na placa: borda, chicote ou solucao hibrida
- orcamento de corrente se o buck deixar de ser modulo pronto

## Fechamento recomendado de protecao para a RevA

Como recomendacao de engenharia para a primeira PCB robusta, usar:

- `F1 1A` na entrada `+12V_OBD`
- `TVS1 = SMCJ24A` unidirecional entre `+12V_PROT` e `GND`
- `D_ESD_CAN1 = PESD2CAN24LT-Q` para `CANH/CANL`
- `D_ESD_K1 = ESDLIN1524BJ` para `K-Line`
- `UREV1 = LM74502-Q1` com `QREV1/QREV2` externos para reversao de polaridade e chaveamento de entrada

Classificacao dessas escolhas:

- `F1 1A`: confirmado na documentacao/EDA existente
- demais itens acima: `inferido / hipotese fortemente recomendada`

Esses componentes entram como baseline proposto para a PCB final, mas nao devem ser descritos como "confirmados no codigo".

## Conflitos e divergencias que nao devem ser resolvidos silenciosamente

1. Narrativas antigas de UI local foram removidas desta rodada.
   - consequencia: para decisao de hardware usar a pinagem real do firmware, nao a narrativa antiga de menus

2. Narrativas antigas de selecao por serial USB foram removidas.
   - consequencia: tratar como historico; o fluxo real atual e `NVS + DIP + UI + web`

3. O firmware nao prova sozinho a existencia fisica de todos os componentes da carrier.
   - consequencia: para liberar esquematico final cruzar sempre firmware com `docs/diagrama-eletrico-pcb.md`, `docs/engenharia-pcb.md`, `docs/reva-carrier-esp32-devkit.md`, handoff CSV e `KiCad RevA`

4. Protecoes automotivas aparecem como recomendacao de engenharia, nao como implementacao fechada da bancada.
   - consequencia: a placa final deve incorporar essas protecoes, mas elas nao podem ser marcadas como "confirmadas no codigo"

## Sequencia recomendada para fechar o esquematico real

1. Use [hardware.md](hardware.md) e [pinout.md](pinout.md) como fonte canonica de requisitos.
2. Use [../hardware/schematic/esquematico-conceitual.md](../hardware/schematic/esquematico-conceitual.md) para estruturar as folhas do projeto.
3. Use [../hardware/schematic/netlist-humana.md](../hardware/schematic/netlist-humana.md) e [../hardware/schematic/bom-preliminar.csv](../hardware/schematic/bom-preliminar.csv) para capturar a conectividade e a lista de componentes.
4. Consulte [../hardware/pcb-handoff/](../hardware/pcb-handoff/) para comparar com o handoff congelado.
5. Continue a captura nativa a partir de [../hardware/kicad/revA/](../hardware/kicad/revA/).

## Observacao operacional importante

O firmware atual contem `SSID`, `hostname` e credenciais default hardcoded em `config.h`. Isso nao foi alterado nesta rodada. Tratar como risco operacional/documental, nao como decisao eletrica de PCB.

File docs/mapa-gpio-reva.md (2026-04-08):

# Mapa Final de GPIO da RevA

## Objetivo

Este documento congela o mapa de GPIO da `RevA` para fechamento do esquematico final.

Ele consolida o mapa de GPIO que deve ser usado como referencia de fechamento para a `PCB RevA`.

## Criterios de fechamento

- manter `CAN`, `K-Line` e `OLED` nos GPIOs ja validados
- remover a UI dos pinos de strapping mais sensiveis do ESP32
- eliminar os LEDs externos redundantes de `CAN` e `K-Line`
- manter apenas `LED_TX` como diagnostico rapido opcional
- preservar `6 botoes`, `encoder`, `DIP` e `OLED`
- simplificar a captura final do `KiCad`

## Mapa final congelado

### Comunicacao OBD

| GPIO | Funcao | Destino |
|---|---|---|
| `GPIO4` | CAN TX | `SN65HVD230 TXD` |
| `GPIO5` | CAN RX | `SN65HVD230 RXD` |
| `GPIO17` | K-Line TX | `L9637D pin 4 (TX)` |
| `GPIO16` | K-Line RX | `L9637D pin 1 (RX)` |

### OLED I2C

| GPIO | Funcao | Destino |
|---|---|---|
| `GPIO21` | I2C SDA | `OLED SDA` |
| `GPIO22` | I2C SCL | `OLED SCL` |

### Botoes

| GPIO | Funcao |
|---|---|
| `GPIO32` | `BTN_PREV` |
| `GPIO33` | `BTN_NEXT` |
| `GPIO25` | `BTN_UP` |
| `GPIO26` | `BTN_DOWN` |
| `GPIO27` | `BTN_SELECT` |
| `GPIO18` | `BTN_PROTOCOL` |

Regra eletrica:

- todos os botoes usam `INPUT_PULLUP` interno
- ligar cada botao entre o GPIO e o `GND`
- nao usar `pull-down` externo nesses botoes

### Encoder

| GPIO | Funcao |
|---|---|
| `GPIO14` | encoder `A / CLK` |
| `GPIO13` | encoder `B / DT` |
| `GPIO19` | encoder `SW` |

Regra eletrica:

- `ENC_SW` segue a mesma logica dos botoes: contato para `GND`
- `GPIO12` e `GPIO15` deixam de ser usados pela UI
- se o modulo `KY-040` tiver `pull-up` onboard em `CLK/DT/SW`, isso e aceitavel nesta revisao porque `GPIO14`, `GPIO13` e `GPIO19` nao sao o problema principal de boot que existia em `GPIO12`

### DIP de protocolo

| GPIO | Bit | Observacao |
|---|---|---|
| `GPIO34` | bit 0 | somente entrada, usar `10k` externo para `3V3` |
| `GPIO35` | bit 1 | somente entrada, usar `10k` externo para `3V3` |
| `GPIO36` | bit 2 | somente entrada, usar `10k` externo para `3V3` |

Leitura:

- chave aberta -> `HIGH`
- chave fechada para `GND` -> `LOW`

### LEDs

| GPIO | LED | Status |
|---|---|---|
| `GPIO23` | `LED_TX` | manter como opcional |
| `GPIO2` | LED onboard | manter |

Remover da `RevA` final:

- `LED_CAN`
- `LED_KLINE`

### GPIOs livres ou reservados

| GPIO | Uso na RevA final | Observacao |
|---|---|---|
| `GPIO12` | nao usar na UI | strapping sensivel no boot |
| `GPIO15` | nao usar na UI | strapping no boot |
| `GPIO39` | livre / reserva | somente entrada; nao necessario nesta revisao |

## Delta em relacao ao rascunho atual do esquema

Aplicar as seguintes trocas para fechar a captura:

1. remover `LED_CAN` de `GPIO19`
2. remover `LED_KLINE` de `GPIO18`
3. mover `BTN_PROTOCOL` para `GPIO18`
4. mover `ENC_SW` para `GPIO19`
5. manter `ENC_A` em `GPIO14`
6. manter `ENC_B` em `GPIO13`
7. recolocar `DIP bit 2` em `GPIO36`
8. deixar `GPIO39` sem obrigacao funcional nesta revisao
9. manter `LED_TX` em `GPIO23` apenas se o LED de trafego rapido continuar desejado

## Justificativa tecnica

### Por que sair de `GPIO12` e `GPIO15`

- `GPIO12` e pino de strapping sensivel no boot do ESP32
- `GPIO15` tambem e pino de strapping
- a UI nao precisa ocupar GPIOs com risco de boot quando existem GPIOs livres apos remover os LEDs redundantes

### Por que remover `LED_CAN` e `LED_KLINE`

- o `OLED` ja mostra protocolo ativo na UI
- os dois LEDs duplicam informacao que ja existe no display
- a tampa de referencia da UI nao reserva abertura especifica para esses LEDs
- liberar `GPIO18` e `GPIO19` resolve a realocacao da UI sem sacrificar barramentos

### Por que manter `LED_TX` opcional

- ele ainda entrega diagnostico visual rapido de trafego
- nao conflita com o mapa final da UI
- pode ser removido depois se a versao mecanica final pedir simplificacao maxima

## Impacto no firmware

O firmware desta branch ja foi alinhado a este mapa nos sinais abaixo:

- `BTN_PROTOCOL`: `GPIO18`
- `ENC_A`: `GPIO14`
- `ENC_SW`: `GPIO19`
- `LED_CAN`: removido do runtime
- `LED_KLINE`: removido do runtime

Nenhuma mudanca adicional de barramento foi necessaria para:

- `CAN`
- `K-Line`
- `OLED`
- `DIP`
- `BTN_PREV`
- `BTN_NEXT`
- `BTN_UP`
- `BTN_DOWN`
- `BTN_SELECT`
- `LED_TX`

## Referencias

- [Pinout canonico](pinout.md)
- [Guia executivo para PCB](engenharia-pcb.md)
- [RevA Carrier para ESP32 DevKit](reva-carrier-esp32-devkit.md)
- [hardware/kicad/revA/ui-panel-reference.csv](../hardware/kicad/revA/ui-panel-reference.csv)

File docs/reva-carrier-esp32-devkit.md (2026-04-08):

# RevA Carrier para ESP32 DevKit

## Decisao congelada da revisao

A revisao `RevA` da PCB do `YouSimuladorOBD` fica oficialmente congelada como:

- `carrier board` para `ESP32 DevKit 38 pinos`
- sem `ESP32-WROOM` soldado diretamente nesta revisao
- mantendo a topologia eletrica ja validada em bancada

Motivacao:

- reutilizar exatamente o modulo MCU que ja foi validado em firmware e bancada
- reduzir risco da primeira rodada de PCB
- facilitar rework e substituicao do MCU em caso de falha
- acelerar a passagem de protoboard para placa real

## Estado atual do programa

O prototipo fisico ja foi montado e validado em bancada com os barramentos alvo da `RevA`.

Status consolidado:

- `CAN`: validado
- `ISO 9141-2`: validado
- `KWP 5-baud`: validado
- `KWP Fast`: validado

Com isso, a `RevA` deixa de ser apenas uma hipotese de handoff e passa a ser a base imediata para a primeira `PCB` orientada a produto.

## Estrategia de integracao da RevA

### MCU

- `MCU1` = `ESP32 DevKit 38 pinos`
- montagem por `2 x headers femea 1x19` com passo `2.54 mm`
- a carrier deve aceitar um `DevKit` comercial de `38 pinos`

Importante:

- antes de fechar `Gerber`, o engenheiro deve confirmar o desenho mecanico do `DevKit` comercial escolhido
- o pinout canonico de bancada e PCB continua documentado em [Pinout Canonico](pinout.md)
- para fechar o esquematico final da `RevA`, usar como referencia primaria [Mapa Final de GPIO da RevA](mapa-gpio-reva.md)

### UI local

Na `RevA`, a estrategia de baixo risco fica:

- `DISP1` como modulo `OLED SH1107 128x128` em header
- `ENC1` como modulo `KY-040` em header
- `SW2-SW7` e `SW1` podem ficar diretamente na carrier
- `LED_TX` pode ficar diretamente na carrier como diagnostico opcional
- `LED_CAN` e `LED_KLINE` deixam de ser obrigatorios no fechamento final

### Fonte e barramentos

Na `RevA`, manter a topologia ja validada:

- entrada `OBD +12V` protegida
- buck `12V -> 5V`
- `SN65HVD230` para CAN
- `L9637D` para K-Line

## Regras mecanicas da carrier

### DevKit

Usar como referencia inicial:

- `2 x 19` pinos
- passo vertical `2.54 mm`
- espacamento nominal entre fileiras `25.40 mm` centro a centro
- keepout nominal do modulo `58 x 31 mm`

Esses valores sao referencia de engenharia da `RevA`. A liberacao final da placa deve confirmar o desenho do `DevKit` real escolhido.

### Keepout obrigatorio da antena

Reservar uma area sem cobre nem componentes na regiao da antena do modulo:

- keepout nominal: `19 x 16 mm`
- sem `GND pour` abaixo da antena
- sem trilhas de alta comutacao, buck ou transceivers nessa zona

### Acesso USB

O `USB` do `DevKit` deve ficar acessivel pela lateral da case ou pela borda da placa.

Recomendacao:

- alinhar o conector USB do `DevKit` a uma borda livre da carrier
- manter folga mecanica para cabo de programacao

## Modulos e conectores recomendados na RevA

| RefDes | Item | Estrategia RevA |
|---|---|---|
| `JMCU1` | header esquerdo do DevKit | `1x19 femea 2.54 mm` |
| `JMCU2` | header direito do DevKit | `1x19 femea 2.54 mm` |
| `JDISP1` | OLED SH1107 | `1x4 header 2.54 mm` |
| `JENC1` | KY-040 | `1x5 header 2.54 mm` |
| `J1` | OBD-II | conector ou chicote na borda |
| `MH1-MH4` | fixacao | furos `M3` |

## Regras eletricas congeladas

### CAN

- `GPIO4` -> `SN65HVD230 TXD`
- `GPIO5` <- `SN65HVD230 RXD`

### K-Line

- `GPIO17` -> `L9637D pin 4`
- `GPIO16` <- `L9637D pin 1`
- `RK1 510R` entre `K` e `VS`
- `RLI1 10k` entre `LI` e `VS`
- `CK1` e `CK2` de `100nF`

### UI

- `GPIO21/22` -> `OLED`
- `GPIO14/13/19` -> `KY-040`
- `GPIO32/33/25/26/27/18` -> botoes
- `GPIO34/35/36` -> DIP
- `GPIO23` -> `LED_TX` opcional
- `GPIO12` e `GPIO15` ficam fora da UI por risco de boot

## Placement de referencia

O placement inicial de referencia para a carrier fica em:

- [hardware/kicad/revA/esp32-devkit38-carrier-reference.csv](../hardware/kicad/revA/esp32-devkit38-carrier-reference.csv)
- [hardware/kicad/revA/ui-panel-reference.csv](../hardware/kicad/revA/ui-panel-reference.csv)

Esses arquivos nao congelam o roteamento final, mas congelam:

- envelope da placa
- keepout do `ESP32 DevKit`
- keepout da antena
- regiao de acesso USB
- regiao do `OLED`
- regiao do `KY-040`
- referencia de alinhamento da UI local

## O que a RevA nao vai fazer

Nesta revisao, nao fazer:

- `ESP32-WROOM` integrado na mesma PCB
- conector `L-Line`
- Bluetooth embarcado
- miniaturizacao agressiva

O objetivo aqui e uma `carrier robusta, de baixo risco e fiel a bancada validada`.

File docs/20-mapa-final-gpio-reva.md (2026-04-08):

# 20 - Mapa Final de GPIO da RevA

## Objetivo

Este documento congela o mapa de GPIO da `RevA` para fechamento do esquematico final.

Ele nao substitui o registro historico da bancada validada. O objetivo aqui e separar:

- o pinout legado que refletia o prototipo de bancada
- o pinout final recomendado para a `PCB RevA`

## Criterios de fechamento

- manter `CAN`, `K-Line` e `OLED` nos GPIOs ja validados
- remover a UI dos pinos de strapping mais sensiveis do ESP32
- eliminar os LEDs externos redundantes de `CAN` e `K-Line`
- manter apenas `LED_TX` como diagnostico rapido opcional
- preservar `6 botoes`, `encoder`, `DIP` e `OLED`
- simplificar a captura final do `KiCad`

## Mapa final congelado

### Comunicacao OBD

| GPIO | Funcao | Destino |
|---|---|---|
| `GPIO4` | CAN TX | `SN65HVD230 TXD` |
| `GPIO5` | CAN RX | `SN65HVD230 RXD` |
| `GPIO17` | K-Line TX | `L9637D pin 4 (TX)` |
| `GPIO16` | K-Line RX | `L9637D pin 1 (RX)` |

### OLED I2C

| GPIO | Funcao | Destino |
|---|---|---|
| `GPIO21` | I2C SDA | `OLED SDA` |
| `GPIO22` | I2C SCL | `OLED SCL` |

### Botoes

| GPIO | Funcao |
|---|---|
| `GPIO32` | `BTN_PREV` |
| `GPIO33` | `BTN_NEXT` |
| `GPIO25` | `BTN_UP` |
| `GPIO26` | `BTN_DOWN` |
| `GPIO27` | `BTN_SELECT` |
| `GPIO18` | `BTN_PROTOCOL` |

Regra eletrica:

- todos os botoes usam `INPUT_PULLUP` interno
- ligar cada botao entre o GPIO e o `GND`
- nao usar `pull-down` externo nesses botoes

### Encoder

| GPIO | Funcao |
|---|---|
| `GPIO14` | encoder `A / CLK` |
| `GPIO13` | encoder `B / DT` |
| `GPIO19` | encoder `SW` |

Regra eletrica:

- `ENC_SW` segue a mesma logica dos botoes: contato para `GND`
- `GPIO12` e `GPIO15` deixam de ser usados pela UI
- se o modulo `KY-040` tiver `pull-up` onboard em `CLK/DT/SW`, isso e aceitavel nesta revisao porque `GPIO14`, `GPIO13` e `GPIO19` nao sao o problema principal de boot que existia em `GPIO12`

### DIP de protocolo

| GPIO | Bit | Observacao |
|---|---|---|
| `GPIO34` | bit 0 | somente entrada, usar `10k` externo para `3V3` |
| `GPIO35` | bit 1 | somente entrada, usar `10k` externo para `3V3` |
| `GPIO36` | bit 2 | somente entrada, usar `10k` externo para `3V3` |

Leitura:

- chave aberta -> `HIGH`
- chave fechada para `GND` -> `LOW`

### LEDs

| GPIO | LED | Status |
|---|---|---|
| `GPIO23` | `LED_TX` | manter como opcional |
| `GPIO2` | LED onboard | manter |

Remover da `RevA` final:

- `LED_CAN`
- `LED_KLINE`

### GPIOs livres ou reservados

| GPIO | Uso na RevA final | Observacao |
|---|---|---|
| `GPIO12` | nao usar na UI | strapping sensivel no boot |
| `GPIO15` | nao usar na UI | strapping no boot |
| `GPIO39` | livre / reserva | somente entrada; nao necessario nesta revisao |

## Delta em relacao ao rascunho atual do esquema

Aplicar as seguintes trocas para fechar a captura:

1. remover `LED_CAN` de `GPIO19`
2. remover `LED_KLINE` de `GPIO18`
3. mover `BTN_PROTOCOL` para `GPIO18`
4. mover `ENC_SW` para `GPIO19`
5. manter `ENC_A` em `GPIO14`
6. manter `ENC_B` em `GPIO13`
7. recolocar `DIP bit 2` em `GPIO36`
8. deixar `GPIO39` sem obrigacao funcional nesta revisao
9. manter `LED_TX` em `GPIO23` apenas se o LED de trafego rapido continuar desejado

## Justificativa tecnica

### Por que sair de `GPIO12` e `GPIO15`

- `GPIO12` e pino de strapping sensivel no boot do ESP32
- `GPIO15` tambem e pino de strapping
- a UI nao precisa ocupar GPIOs com risco de boot quando existem GPIOs livres apos remover os LEDs redundantes

### Por que remover `LED_CAN` e `LED_KLINE`

- o `OLED` ja mostra protocolo ativo na UI
- os dois LEDs duplicam informacao que ja existe no display
- a tampa de referencia da UI nao reserva abertura especifica para esses LEDs
- liberar `GPIO18` e `GPIO19` resolve a realocacao da UI sem sacrificar barramentos

### Por que manter `LED_TX` opcional

- ele ainda entrega diagnostico visual rapido de trafego
- nao conflita com o mapa final da UI
- pode ser removido depois se a versao mecanica final pedir simplificacao maxima

## Impacto no firmware

O firmware desta branch ja foi alinhado a este mapa nos sinais abaixo:

- `BTN_PROTOCOL`: `GPIO18`
- `ENC_A`: `GPIO14`
- `ENC_SW`: `GPIO19`
- `LED_CAN`: removido do runtime
- `LED_KLINE`: removido do runtime

Nenhuma mudanca adicional de barramento foi necessaria para:

- `CAN`
- `K-Line`
- `OLED`
- `DIP`
- `BTN_PREV`
- `BTN_NEXT`
- `BTN_UP`
- `BTN_DOWN`
- `BTN_SELECT`
- `LED_TX`

## Referencias

- [03 - Pinout ESP32 e Ligacoes](03-pinout.md)
- [16 - Pacote para o Engenheiro de PCB](16-pacote-engenheiro-pcb.md)
- [17 - RevA Carrier para ESP32 DevKit](17-revA-carrier-esp32-devkit.md)
- [hardware/kicad/revA/ui-panel-reference.csv](../hardware/kicad/revA/ui-panel-reference.csv)

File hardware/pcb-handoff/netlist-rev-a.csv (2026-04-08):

Net | RefDes | Pin | Role | Notes
+12V_OBD | J1 | 16 | source | Entrada principal da bateria OBD
+12V_OBD | F1 | 1 | input | Fusivel de entrada
+12V_PROT | F1 | 2 | output | Saida protegida do fusivel
+12V_PROT | U1 | IN+ | power | Entrada do LM2596
+12V_PROT | U3 | 7 | VS | Alimentacao automotiva do L9637D
+12V_PROT | RK1 | 1 | source | Pull-up da linha K
+12V_PROT | RLI1 | 1 | source | Bias da linha LI
GND | J1 | 4 | source | Chassis GND
GND | J1 | 5 | source | Signal GND
GND | U1 | IN- | power | GND do LM2596
GND | U1 | OUT- | power | GND de saida do LM2596
GND | MCU1 | GND | common | GND do ESP32
GND | U2 | 2 | power | GND do SN65HVD230
GND | U2 | 8 | config | RS em GND para modo rapido
GND | U3 | 5 | power | GND do L9637D
GND | CK1 | 2 | decoupling | Retorno do VCC do L9637D
GND | CK2 | 2 | decoupling | Retorno do VS do L9637D
GND | DISP1 | GND | power | GND do OLED
GND | ENC1 | GND | power | GND do encoder
GND | SW2-SW7 | 2 | return | Botoes para GND
GND | SW1 | common | return | DIP fecha para GND
GND | D3 | K | return | Retorno do LED_TX opcional
+5V_SYS | U1 | OUT+ | power | Saida 5V do buck
+5V_SYS | MCU1 | VIN | power | Entrada 5V do ESP32
+5V_SYS | U4 | IN | power | Entrada do regulador 3.3V dedicado
+3V3_AUX | U4 | OUT | source | Saida 3.3V auxiliar dedicada
+3V3_AUX | U2 | 3 | power | VCC do SN65HVD230
+3V3_AUX | U3 | 3 | power | VCC logico do L9637D
+3V3_AUX | DISP1 | VCC | power | OLED
+3V3_AUX | ENC1 | VCC | power | Encoder
+3V3_AUX | RDIP1 | 1 | pullup | DIP bit0
+3V3_AUX | RDIP2 | 1 | pullup | DIP bit1
+3V3_AUX | RDIP3 | 1 | pullup | DIP bit2
CAN_TX_LOGIC | MCU1 | GPIO4 | source | CAN TX do ESP32
CAN_TX_LOGIC | U2 | 1 | input | SN65HVD230 TXD
CAN_RX_LOGIC | U2 | 4 | output | SN65HVD230 RXD
CAN_RX_LOGIC | MCU1 | GPIO5 | input | CAN RX do ESP32
CANH | U2 | 7 | bus | CAN High
CANH | J1 | 6 | bus | OBD CAN High
CANL | U2 | 6 | bus | CAN Low
CANL | J1 | 14 | bus | OBD CAN Low
CAN_TERM | RCAN1 | 1 | optional | Terminacao opcional entre CANH e CANL
CAN_TERM | RCAN1 | 2 | optional | Terminacao opcional entre CANH e CANL
K_TX_LOGIC | MCU1 | GPIO17 | source | K-Line TX logico
K_TX_LOGIC | U3 | 4 | input | TX do L9637D
K_RX_LOGIC | U3 | 1 | output | RX do L9637D
K_RX_LOGIC | MCU1 | GPIO16 | input | K-Line RX logico
KLINE | U3 | 6 | bus | Linha K
KLINE | J1 | 7 | bus | OBD K-Line
KLINE | RK1 | 2 | pullup | Ponto puxado para VS por 510R
LI_BIAS | U3 | 8 | input | LI do L9637D
LI_BIAS | RLI1 | 2 | bias | Resistor de 10k para VS
CK1_VCC | U3 | 3 | decoupling | VCC do L9637D
CK1_VCC | CK1 | 1 | decoupling | 100nF para GND
CK2_VS | U3 | 7 | decoupling | VS do L9637D
CK2_VS | CK2 | 1 | decoupling | 100nF para GND
I2C_SDA | MCU1 | GPIO21 | signal | OLED SDA
I2C_SDA | DISP1 | SDA | signal | OLED SDA
I2C_SCL | MCU1 | GPIO22 | signal | OLED SCL
I2C_SCL | DISP1 | SCL | signal | OLED SCL
ENC_A | MCU1 | GPIO14 | signal | Encoder CLK
ENC_A | ENC1 | CLK | signal | Encoder CLK
ENC_B | MCU1 | GPIO13 | signal | Encoder DT
ENC_B | ENC1 | DT | signal | Encoder DT
ENC_SW | MCU1 | GPIO19 | signal | Encoder SW
ENC_SW | ENC1 | SW | signal | Encoder SW
BTN_PREV | MCU1 | GPIO32 | input | Input pull-up interno
BTN_NEXT | MCU1 | GPIO33 | input | Input pull-up interno
BTN_UP | MCU1 | GPIO25 | input | Input pull-up interno
BTN_DOWN | MCU1 | GPIO26 | input | Input pull-up interno
BTN_SELECT | MCU1 | GPIO27 | input | Input pull-up interno
BTN_PROTOCOL | MCU1 | GPIO18 | input | Input pull-up interno
DIP_BIT0 | MCU1 | GPIO34 | input | Somente entrada
DIP_BIT0 | RDIP1 | 2 | pullup | 10k para +3V3_AUX
DIP_BIT0 | SW1 | 1 | switch | Fecha para GND
DIP_BIT1 | MCU1 | GPIO35 | input | Somente entrada
DIP_BIT1 | RDIP2 | 2 | pullup | 10k para +3V3_AUX
DIP_BIT1 | SW1 | 2 | switch | Fecha para GND
DIP_BIT2 | MCU1 | GPIO36 | input | Somente entrada
DIP_BIT2 | RDIP3 | 2 | pullup | 10k para +3V3_AUX
DIP_BIT2 | SW1 | 3 | switch | Fecha para GND
LED_TX | MCU1 | GPIO23 | source | LED de trafego
LED_TX | RLED3 | 1 | series | 330R

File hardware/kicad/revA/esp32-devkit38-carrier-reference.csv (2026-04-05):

Feature | Reference | X_mm | Y_mm | Width_mm | Height_mm | Pitch_mm | Notes
Carrier_Outline | PCB | 0 | 0 | 115 | 80 |  | Envelope inicial sugerido da carrier RevA
DevKit_Keepout | MCU1 | 18 | 22 | 58 | 31 |  | Keepout nominal do modulo ESP32 DevKit 38p
Header_Left | JMCU1 | 22 | 17 |  |  | 2.54 | Header femea 1x19 lado esquerdo do DevKit
Header_Right | JMCU2 | 47.4 | 17 |  |  | 2.54 | Header femea 1x19 lado direito com espacamento nominal de 25.40 mm
USB_Access | MCU1 | 9 | 28 | 11 | 13 |  | Area livre para acesso ao conector USB do DevKit
Antenna_Keepout | MCU1 | 56 | 24 | 19 | 16 |  | Sem cobre nem componentes abaixo da antena do modulo
OLED_Header | JDISP1 | 41 | 63 |  |  | 2.54 | Header 1x4 do OLED alinhado ao frontal
Encoder_Header | JENC1 | 86 | 54 |  |  | 2.54 | Header 1x5 do KY-040 alinhado ao eixo do encoder
Buttons_Row | SW2-SW7 | 24 | 17 | 78 | 12 |  | Faixa mecanica dos 6 botoes do frontal
OBD_Zone | J1 | 90 | 8 | 23 | 20 |  | Zona recomendada do conector OBD ou chicote
Buck_Zone | U1 | 83 | 55 | 28 | 22 |  | Zona do LM2596 ou footprint equivalente
CAN_Zone | U2 | 12 | 55 | 18 | 12 |  | SN65HVD230 | terminacao e protecao CAN
KLine_Zone | U3 | 12 | 38 | 18 | 14 |  | L9637D | RK1 | RLI1 | CK1 e CK2
Mounting_Hole_1 | MH1 | 5 | 5 |  |  | 3.2 | Furo M3
Mounting_Hole_2 | MH2 | 110 | 5 |  |  | 3.2 | Furo M3
Mounting_Hole_3 | MH3 | 5 | 75 |  |  | 3.2 | Furo M3
Mounting_Hole_4 | MH4 | 110 | 75 |  |  | 3.2 | Furo M3

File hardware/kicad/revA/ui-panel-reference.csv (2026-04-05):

Feature | Reference | X_mm | Y_mm | Width_mm | Height_mm | Diameter_mm | Notes
Lid | Origin | 0 | 0 | 132 | 97 |  | Origem no canto inferior esquerdo da tampa
OLED_Window | DISP1 | 49 | 49 | 34 | 34 |  | Janela visivel quadrada SH1107 128x128
OLED_Bezel | DISP1 | 45 | 41 | 42 | 42 |  | Rebaixo raso ao redor da janela
Button_1 | SW2_PREV | 31 | 26 |  |  | 6.5 | Furo do botao PREV
Button_2 | SW3_NEXT | 45 | 26 |  |  | 6.5 | Furo do botao NEXT
Button_3 | SW4_UP | 59 | 26 |  |  | 6.5 | Furo do botao UP
Button_4 | SW5_DOWN | 73 | 26 |  |  | 6.5 | Furo do botao DOWN
Button_5 | SW6_OK | 87 | 26 |  |  | 6.5 | Furo do botao OK
Button_6 | SW7_PROTO | 101 | 26 |  |  | 6.5 | Furo do botao PROTO
Encoder_Shaft | ENC1 | 103 | 53 |  |  | 7.4 | Furo do eixo do encoder KY-040
Encoder_Clearance | ENC1 | 94.5 | 44.5 | 17 | 17 |  | Rebaixo circular para a area do knob

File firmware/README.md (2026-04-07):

# Firmware

Este diretorio contem o firmware embarcado do `YouSimuladorOBD`.

## Build

Comandos principais:

```bash
cd firmware
pio run
```

## Upload

```bash
cd firmware
pio run -t upload
pio run -t uploadfs
```

Ferramentas uteis:

```bash
cd firmware
pio device monitor
pio run -t size
```

## Estrutura interna

```text
firmware/
|- include/
|- src/
|  |- obd/
|  |- protocols/
|  |- simulation/
|  `- web/
|- data/
`- platformio.ini
```

## Arquivos mais importantes

- `include/config.h`
  - mapa central de GPIOs e constantes principais
- `src/main.cpp`
  - boot, leitura do DIP, restauracao de protocolo/perfil e subida das tasks
- `src/protocols/can_protocol.cpp`
  - transporte OBD sobre CAN/TWAI
- `src/protocols/kline_protocol.cpp`
  - transporte OBD sobre K-Line/UART1
- `src/web/ui_init.cpp`
  - UI local com OLED, botoes e encoder
- `src/web/web_server.cpp`
  - Wi-Fi, Web UI, API, WebSocket, mDNS e OTA

## Dependencias principais

Declaradas em `platformio.ini`:

- `ESPAsyncWebServer-esphome`
- `ArduinoJson`
- `Adafruit SH110X`
- `Adafruit GFX`
- `Adafruit BusIO`
- `ESP32Encoder`
- `Bounce2`

Tambem usa bibliotecas nativas do ecossistema ESP32:

- `Preferences`
- `Wire`
- `ESPmDNS`
- `LittleFS`
- `Update`
- `WiFi`
- `WiFiClientSecure`

## Arquivos de configuracao eletrica

Para qualquer manutencao ligada a hardware, comecar por:

- `include/config.h`
- `src/main.cpp`
- `src/protocols/can_protocol.cpp`
- `src/protocols/kline_protocol.cpp`
- `src/web/ui_init.cpp`

Se algum GPIO mudar no futuro, atualizar junto:

- `../docs/hardware.md`
- `../docs/pinout.md`

## Observacoes praticas

- a estrutura interna de `firmware/` foi preservada nesta rodada para evitar risco de quebrar build
- esta revisao usa `ESP32 DevKit 38 pinos` como baseline, nao `ESP32-WROOM` integrado
- o firmware usa `Wi-Fi`, mas nao usa `BLE/Bluetooth` de forma ativa nesta revisao
- `SSID`, `hostname` e a credencial fixa do sistema continuam definidos no firmware e devem ser tratados como risco operacional/documental

## Dados web em flash

A pasta `data/` contem os arquivos servidos pelo `LittleFS`, como:

- `index.html`
- `ota.html`

Se houver mudanca relevante na UI web:

1. atualizar os arquivos em `data/`
2. reexecutar `pio run`
3. se necessario, subir o filesystem com `pio run -t uploadfs`

## Web UI em bancada

Comportamento esperado da interface web atual:

- `WebSocket` e o caminho preferencial para atualizacao em tempo real
- se o `WebSocket` oscilar ou cair, a UI usa `HTTP` como fallback
- o fallback cobre:
  - status
  - diagnostico
  - cenarios
  - protocolo
  - modo
  - presets
  - sliders e parametros

Autenticacao em bancada:

- todas as rotas `/api/*` exigem autenticacao valida no dispositivo ativo
- Web/OTA e API usam a mesma credencial fixa definida em `include/config.h`
- a UI de OTA nao rotaciona nem sobrescreve mais as credenciais em runtime
- hostname e manifest OTA continuam persistentes, mas login e senha nao divergem mais por NVS

Checklist rapido antes de culpar a API ou o frontend:

1. abrir `http://youobd2.local` e confirmar login normal na Web UI
2. confirmar a credencial fixa vigente em `include/config.h` ou no procedimento interno da bancada
3. validar a autenticacao antes de usar `GET /api/status`, `GET /api/diagnostics` ou `GET /api/scenarios` como oracle automatizado

Checklist pratico de validacao apos mexer na UI:

1. abrir `http://youobd2.local`
2. confirmar que o `Perfil do Veiculo` carrega
3. confirmar que a lista de `Camada Diagnostica` carrega
4. testar troca de `Modo de Simulacao`
5. testar aplicacao e limpeza de um cenario
6. testar um slider qualquer e conferir atualizacao de estado

Se o firmware mudou e a UI tambem mudou:

1. `pio run -t upload`
2. `pio run -t uploadfs`

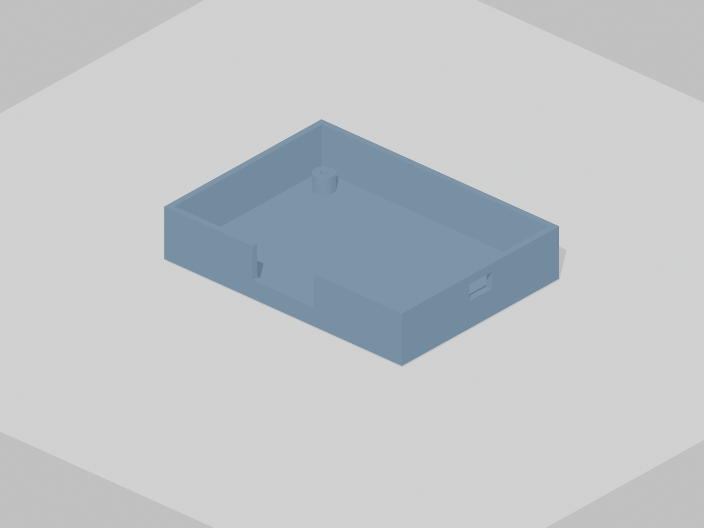
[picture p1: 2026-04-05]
hardware/cad/renders/bench_case_revA_base.png

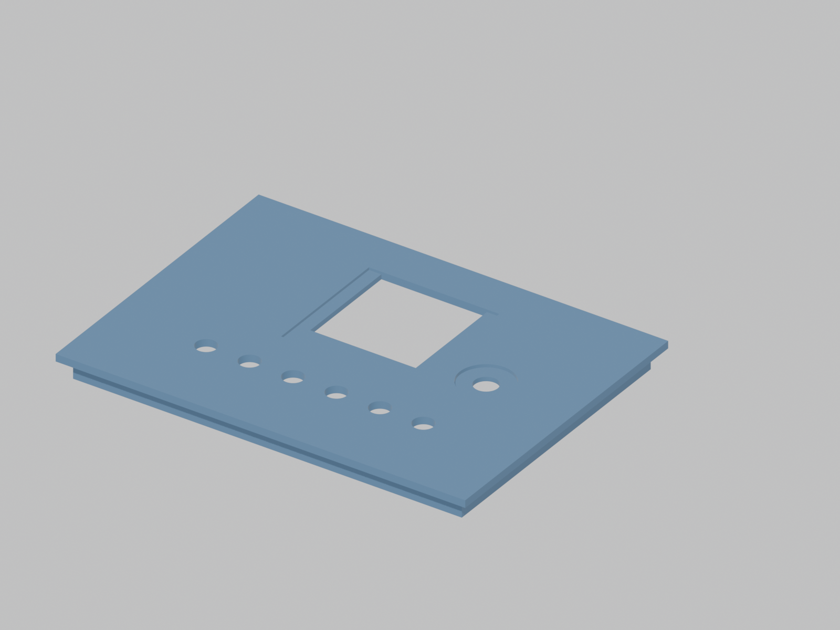
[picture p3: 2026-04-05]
hardware/cad/renders/bench_case_revA_lid_ui.png

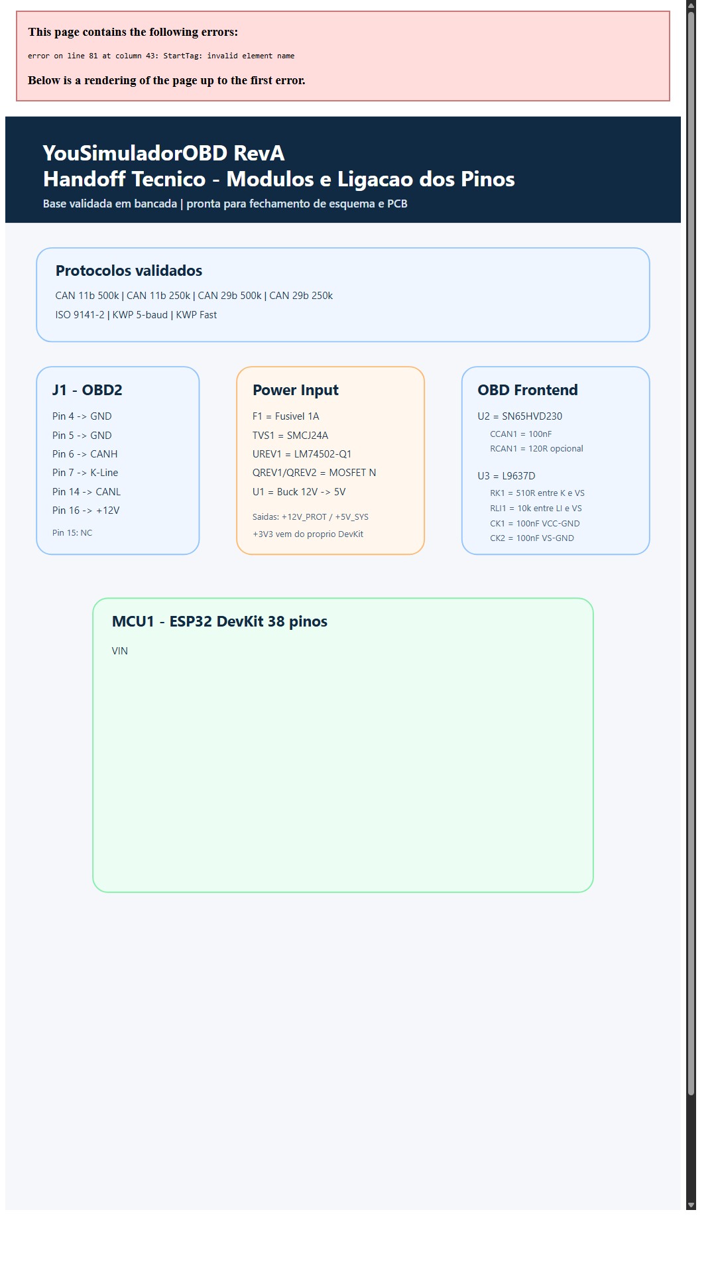
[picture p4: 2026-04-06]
docs/img/reva-handoff-vertical.jpg

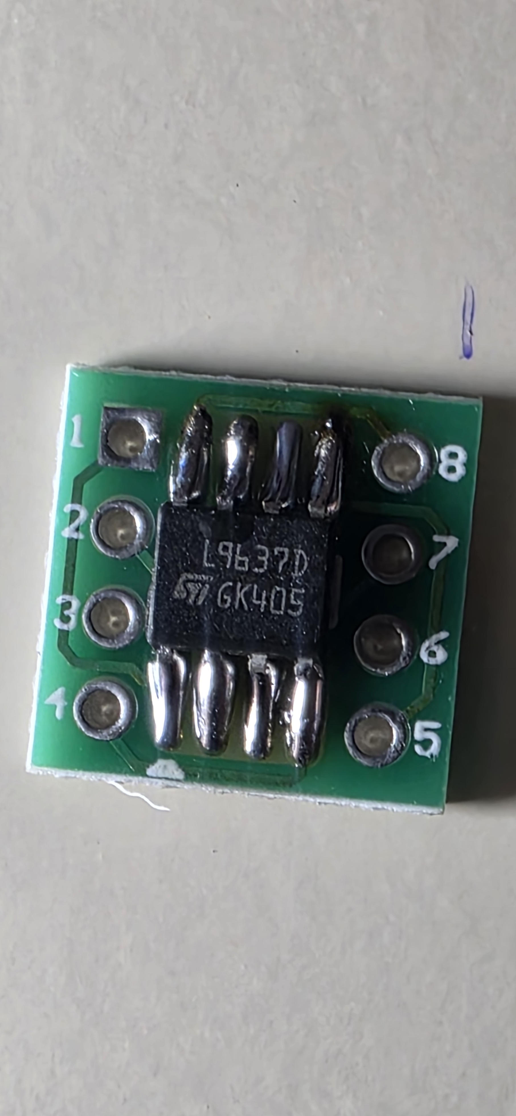
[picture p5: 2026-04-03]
docs/img/l9637d-adaptador-real.jpg

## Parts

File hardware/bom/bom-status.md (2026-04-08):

# BOM - Status Consolidado dos Componentes

Atualizado: `2026-04-08`

Este arquivo deixou de ser apenas uma lista de compras e passou a registrar o conjunto de referencia da `RevA`, separando o que ja foi validado do que foi fechado para o esquematico final.

## Conjunto validado

| RefDes | Componente | Estado |
|---|---|---|
| `MCU1` | `ESP32 DevKit` 38 pinos | Validado |
| `U1` | `LM2596` buck 12V -> 5V | Validado |
| `U4` | regulador `3.3V` dedicado para `+3V3_AUX` | Fechar na RevA |
| `U2` | `SN65HVD230` | Validado |
| `U3` | `L9637D` | Validado |
| `J1` | conector OBD-II femea 16 pinos | Validado |
| `DISP1` | `OLED SH1107 128x128` | Validado |
| `ENC1` | `KY-040` | Validado |
| `SW1` | DIP 3 bits | Validado |
| `SW2-SW7` | 6 botoes | Validado |
| `D3` | `LED_TX` opcional | Opcional na RevA |

## Passivos criticos

| RefDes | Valor | Estado | Observacao |
|---|---|---|---|
| `RK1` | `510R` | Obrigatorio | pull-up de `K -> VS`, usar `>= 0.5W` |
| `RLI1` | `10k` | Obrigatorio | `LI -> VS` no `L9637D` |
| `CK1` | `100nF` | Obrigatorio | `VCC -> GND` no `L9637D` |
| `CK2` | `100nF` | Obrigatorio | `VS -> GND` no `L9637D` |
| `RCAN1` | `120R` | Recomendado | terminacao CAN por jumper ou `DNP` |
| `RDIP1-RDIP3` | `10k` | Obrigatorio | pull-up externo do DIP |
| `RLED3` | `330R` | Opcional | `LED_TX` |
| `F1` | `1A` | Obrigatorio | entrada +12V |

## Componentes que ficaram obsoletos

Os itens abaixo nao sao mais a referencia principal do projeto:

- circuito discreto de K-Line com transistor NPN
- qualquer esquema antigo que mostre K-Line direto por transistor
- arquivos antigos em `hardware/schematic/` sem o `L9637D`

## Arquivos corretos para o engenheiro

Use para a PCB:

- [docs/diagrama-eletrico-pcb.md](../../docs/diagrama-eletrico-pcb.md)
- [hardware/pcb-handoff/README.md](../pcb-handoff/README.md)

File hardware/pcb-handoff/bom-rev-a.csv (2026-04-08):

RefDes | Qty | Part | Value_or_Model | Package_or_Form | Notes
J1 | 1 | OBD-II connector | Female 16-pin | Harness or PCB connector | Main OBD interface
F1 | 1 | Fuse | 1A | Automotive or radial | Protect +12V input
U1 | 1 | Buck regulator module | LM2596 | Module or equivalent | 12V to 5V
U4 | 1 | 3.3V regulator | AMS1117-3.3 or equivalent | SOT-223 or equivalent | Dedicated +3V3_AUX for peripherals
MCU1 | 1 | MCU board or module | ESP32 DevKit 38p | Pluggable module | RevA frozen as carrier board
JMCU1 | 1 | Female header | 1x19 2.54mm | Through-hole | ESP32 DevKit left row
JMCU2 | 1 | Female header | 1x19 2.54mm | Through-hole | ESP32 DevKit right row
U2 | 1 | CAN transceiver | SN65HVD230 | SOIC-8 | 3.3V native CAN transceiver
U3 | 1 | K-Line transceiver | L9637D | SOIC-8 | K-Line physical layer
RK1 | 1 | Resistor | 510R | >=0.5W | Pull-up K to VS
RLI1 | 1 | Resistor | 10k | 1/4W or SMD | Bias LI to VS
CK1 | 1 | Capacitor | 100nF | X7R 50V | Place close to U3 VCC-GND
CK2 | 1 | Capacitor | 100nF | X7R 50V | Place close to U3 VS-GND
CCAN1 | 1 | Capacitor | 100nF | X7R 16V | Place close to U2 VCC-GND
RCAN1 | 1 | Resistor | 120R | Optional / jumper | Selectable CAN termination
DISP1 | 1 | OLED display | SH1107 128x128 | I2C module | 3.3V
JDISP1 | 1 | Pin header | 1x4 2.54mm | Through-hole | OLED module header for RevA carrier
ENC1 | 1 | Rotary encoder | KY-040 | Module or encoder footprint | UI input
JENC1 | 1 | Pin header | 1x5 2.54mm | Through-hole | KY-040 module header for RevA carrier
SW1 | 1 | DIP switch | 3-position | Through-hole or SMD | Protocol bits
RDIP1-RDIP3 | 3 | Resistor | 10k | 1/4W or SMD | Pull-up for GPIO34/35/36
SW2-SW7 | 6 | Push button | Momentary | Through-hole or SMD | Connected to GND
D3 | 1 | LED | Status LED optional | 3mm or SMD | TX / trafego
RLED3 | 1 | Resistor | 330R | 1/4W or SMD | LED_TX series resistor
MH1-MH4 | 4 | Mounting hole | M3 | NPTH or plated mechanical | Board fixation

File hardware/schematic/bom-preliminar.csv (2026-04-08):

RefDes | Componente | Valor / Modelo | Função | Encapsulamento sugerido | Observações
J1 | Conector OBD-II | J1962 femea 16 vias | Interface automotiva externa | Conector de borda ou chicote | Modelo exato a confirmar antes do layout final
F1 | Fusivel de entrada | 1A | Protecao primaria da linha +12V | Automotivo radial ou SMD de potencia | Confirmado na documentacao/EDA existente; part number final em aberto
TVS1 | TVS automotiva | SMCJ24A unidirecional | Protecao contra surto na entrada +12V | DO-214AB (SMCJ) | Recomendacao de engenharia para RevA final; nao confirmada como item da bancada base
UREV1 | Controlador de reversao de polaridade | LM74502-Q1 | Protecao contra inversao de polaridade e load disconnect | SOT-23-THIN-8 (DDF) | Recomendacao de engenharia para RevA final; requer MOSFETs externos
QREV1,QREV2 | MOSFET N de entrada | 40V a 60V logic-level | Par back-to-back comandado por UREV1 | SO-8 PowerPAK ou DFN de potencia | Part number final depende da corrente alvo e da dissipacao
U1 | Buck regulator | LM2596 ou equivalente | Conversao 12V para 5V | Modulo ou footprint equivalente | Baseline confirmado na documentacao/EDA existente
U4 | Regulador 3.3V dedicado | AMS1117-3.3 ou equivalente | Gera +3V3_AUX para perifericos | SOT-223 ou equivalente | Separar alimentacao dos perifericos do 3V3 do DevKit
MCU1 | Modulo MCU | ESP32 DevKit 38 pinos | MCU principal | Modulo comercial plugavel | RevA congelada como carrier para DevKit
JMCU1 | JMCU2 | Headers femea | 1x19 2.54 mm | Carrier do ESP32 DevKit | Through-hole | Confirmar geometria com o DevKit comercial final
U2 | Transceiver CAN | SN65HVD230 | Interface fisica CAN | SOIC-8 | Confirmado na documentacao/EDA existente
CCAN1 | Capacitor de desacoplamento | 100nF | Desacoplamento local do U2 | X7R 16V ou superior | Colocar junto do U2
RCAN1 | Resistor de terminacao | 120R | Terminacao CAN opcional | 1206 ou jumper | DNP ou jumper conforme estrategia final de barramento
D_ESD_CAN1 | Protetor ESD automotivo para CAN | PESD2CAN24LT-Q | Protecao de CANH e CANL | SOT23 | Recomendacao de engenharia para RevA final; posicionar junto de J1
U3 | Transceiver K-Line | L9637D | Interface fisica K-Line | SOIC-8 | Confirmado na documentacao/EDA existente
RK1 | Resistor | 510R | Pull-up de K para VS | >= 0.5W axial ou SMD de potencia | Obrigatorio para reproduzir a bancada validada
RLI1 | Resistor | 10k | Bias de LI para VS | 0805 ou 1206 | Obrigatorio para reproduzir a bancada validada
CK1 | Capacitor | 100nF | Desacoplamento VCC do L9637D | X7R 50V | Colocar encostado em U3 VCC-GND
CK2 | Capacitor | 100nF | Desacoplamento VS do L9637D | X7R 50V | Colocar encostado em U3 VS-GND
D_ESD_K1 | Protetor ESD automotivo para K-Line | ESDLIN1524BJ | Protecao da linha K | SOD323 | Recomendacao de engenharia para RevA final; posicionar junto de J1 pin 7
DISP1 | Display OLED | SH1107 128x128 modulo | Interface local visual | Modulo I2C por header | Footprint final depende do modulo real escolhido
JDISP1 | Header do OLED | 1x4 2.54 mm | Conexao do modulo OLED | Through-hole | RevA usa modulo por header
ENC1 | Encoder rotativo | KY-040 | Entrada de navegacao local | Modulo ou footprint equivalente | Footprint final depende do modulo real escolhido
JENC1 | Header do encoder | 1x5 2.54 mm | Conexao do modulo encoder | Through-hole | RevA usa modulo por header
SW1 | DIP switch | 3 posicoes | Selecao de protocolo no boot | Through-hole ou SMD | Confirmado na documentacao/EDA existente
RDIP1-RDIP3 | Resistores de pull-up | 10k | Pull-up externo dos GPIO34-36 | 0805 ou 1206 | Obrigatorio porque esses GPIOs nao tem pull-up interno
SW2-SW7 | Botoes momentaneos | Tact switch | Interface local | Through-hole ou SMD | Seis botoes: PREV NEXT UP DOWN OK PROTO
D3 | LED de status opcional | LED 3 mm ou SMD | Indicacao de TX | 3 mm THT ou 0805/1206 | Escolha conforme painel mecanico
RLED3 | Resistor serie de LED | 330R | Limitacao de corrente do LED_TX | 0805 ou 1206 | Confirmado na documentacao/EDA existente
MH1-MH4 | Furos de fixacao | M3 | Fixacao da placa | NPTH M3 | Confirmados na documentacao/EDA existente
TP1-TP9 | Pontos de teste | Test point | Depuracao de bancada | Test point SMD ou pino | Minimos recomendados: +12V +5V +3V3_AUX GND CANH CANL K TX_K RX_K

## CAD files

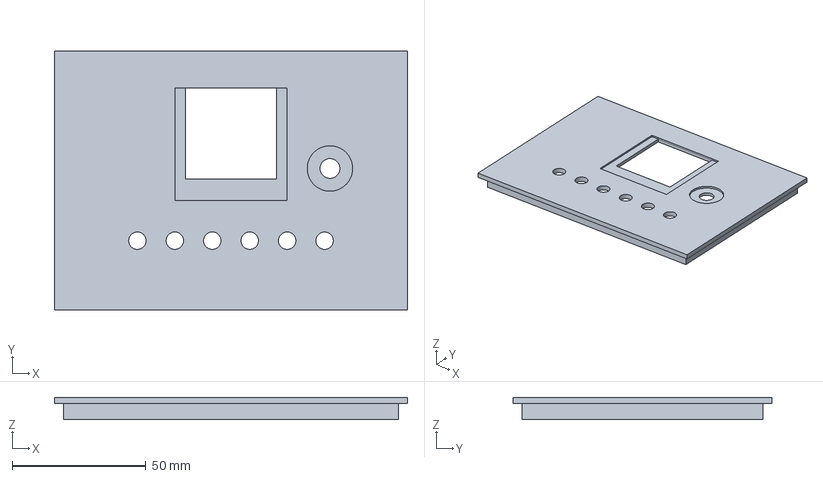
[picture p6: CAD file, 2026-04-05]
hardware/cad/freecad/bench_case_revA_lid_ui.step
132.0 x 97.0 x 8.40 mm

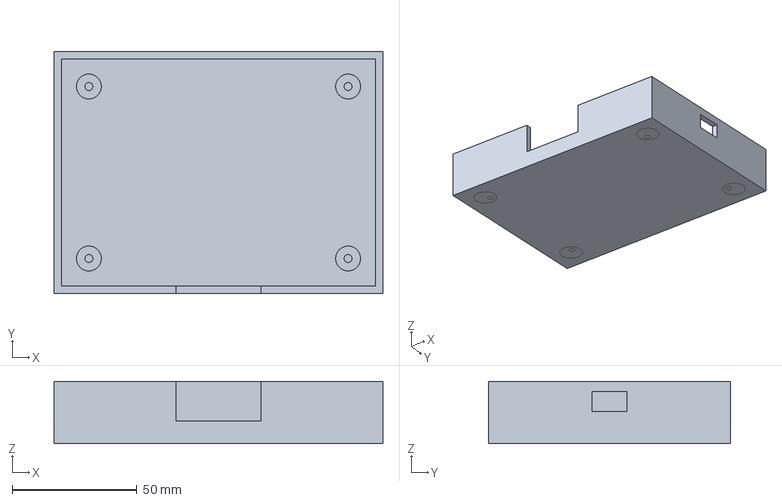
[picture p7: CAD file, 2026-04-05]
hardware/cad/freecad/bench_case_revA_base.step
132.0 x 97.0 x 25.0 mm

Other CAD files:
hardware/cad/freecad/bench_case_revA_base.FCStd
hardware/cad/freecad/bench_case_revA_base.stl
hardware/cad/freecad/bench_case_revA_lid_ui.FCStd
hardware/cad/freecad/bench_case_revA_lid_ui.stl

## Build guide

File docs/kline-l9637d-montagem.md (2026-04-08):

# Montagem K-Line com L9637D

## Objetivo

Registrar a montagem final e validada da interface `K-Line` usando `L9637D`, incluindo o que realmente funcionou em bancada.

Esta e a referencia correta para:

- perfboard
- bancada
- captura de esquema para PCB

## Componentes obrigatorios

| RefDes | Valor | Funcao |
|---|---|---|
| `U3` | `L9637D` | transceiver K-Line |
| `RK1` | `510R` | pull-up de `K -> VS`, usar `>= 0.5W` |
| `RLI1` | `10k` | bias de `LI -> VS` |
| `CK1` | `100nF` | `VCC -> GND` |
| `CK2` | `100nF` | `VS -> GND` |

## Pinagem do L9637D

Top view:

```text
         .---U3 L9637D---.
RX    1 -|               |- 8 LI
LO    2 -|               |- 7 VS
VCC   3 -|               |- 6 K
TX    4 -|               |- 5 GND
         '---------------'
```

## Ligacao final validada

| Pin U3 | Nome | Liga em | Estado |
|---|---|---|---|
| `1` | `RX` | `ESP32 GPIO16` | usado |
| `2` | `LO` | `NC` | nao usado |
| `3` | `VCC` | `+3V3_AUX` | usado |
| `4` | `TX` | `ESP32 GPIO17` | usado |
| `5` | `GND` | `GND comum` | usado |
| `6` | `K` | `OBD pin 7` | usado |
| `7` | `VS` | `OBD pin 16 (+12V)` | usado |
| `8` | `LI` | `10k -> VS` | usado |

Passivos:

- `RK1 510R`: entre `pin 6 (K)` e `pin 7 (VS)`
- `CK1 100nF`: entre `pin 3 (VCC)` e `pin 5 (GND)`
- `CK2 100nF`: entre `pin 7 (VS)` e `pin 5 (GND)`

## Resumo visual da ligacao

```text
ESP32 GPIO17  -> U3 pin 4 (TX)
ESP32 GPIO16  <- U3 pin 1 (RX)
+3V3_AUX      -> U3 pin 3 (VCC)
ESP32 GND     -> U3 pin 5 (GND)

OBD pin 7     -> U3 pin 6 (K)
OBD pin 16    -> U3 pin 7 (VS)
OBD pin 4/5   -> GND comum

U3 pin 8 (LI) -> 10k -> U3 pin 7 (VS)
U3 pin 6 (K)  -> 510R -> U3 pin 7 (VS)
```

## Medidas aceitas em repouso

Com a placa ligada, sem trafego:

- `U3 pin 4 (TX) -> GND`: `~3.3V`
- `U3 pin 6 (K) -> GND`: `~12.23V`
- `U3 pin 1 (RX) -> GND`: `~3.317V`

Se isso nao acontecer, revisar primeiro:

- `VS +12V`
- `RK1 510R`
- `GPIO17`
- `GPIO16`
- solda do `L9637D`

## Teste passivo do CI

Com a placa desligada, o CI aprovado mostrou:

- `pin 3 -> pin 5`: alta resistencia
- `pin 7 -> pin 5`: `OL`
- `pin 6 -> pin 5`: `OL`
- `pin 6 -> pin 7`: `OL`

Esse teste ajuda a descartar curto grosseiro.

## Teste funcional isolado do CI

Teste de bancada que aprovou o `L9637D`:

1. alimentar:
   - `pin 3 = +3V3_AUX`
   - `pin 5 = GND`
   - `pin 7 = +12V`
   - `pin 8 -> 10k -> pin 7`
   - `pin 6 -> 510R -> pin 7`
2. forcar `pin 4` por resistor de `1k`

Resultado esperado:

- `pin 4` em alto -> `pin 6` perto de `12V`
- `pin 4` em baixo -> `pin 6` perto de `0V`

Esse teste foi o que comprovou que o CI estava funcional e orientado corretamente.

## Problemas reais encontrados na bancada

### 1. Sem `510R` em `K -> VS`

Sintoma:

- `BUS INIT ERROR`
- linha K sem idle alto confiavel

Correcao:

- adicionar `510R` entre `pin 6` e `pin 7`

### 2. Sem os dois `100nF`

Sintoma:

- bring-up mais sensivel a ruido
- init instavel

Correcao:

- adicionar `CK1` e `CK2`

### 3. Protocolo errado no boot

Sintoma:

- placa parecia voltar para `ISO 9141-2` ou outro protocolo apos reset

Correcao:

- persistir o protocolo escolhido em NVS

## Estado final aceito

- `ISO 9141-2`: validado
- `KWP Fast`: validado
- `KWP 5-baud`: validado

Observacao:

- com o aceite de `ISO 9141-2`, `KWP Fast` e `KWP 5-baud`, este bloco `K-Line` deve ser tratado como base fechada para a captura da `RevA`

## Recomendacao para a placa de circuito impresso

- manter o `L9637D` perto do conector OBD
- manter `CK1` e `CK2` encostados no CI
- usar `RK1` com folga termica
- deixar ponto de teste em `K`, `TX_K`, `RX_K`, `VS` e `GND`
- tratar este circuito como baseline de produto, nao mais apenas como experimento de bancada

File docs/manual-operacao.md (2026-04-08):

# Manual de Operacao

Manual pratico para uso diario do `YouSimuladorOBD` em bancada, campo e desenvolvimento com `YouAutoCarvAPP2`, `Torque Pro`, `OBDLink` e plugin `YOU OBD Lab`.

## 1. Objetivo

Este manual cobre:

- acesso ao painel web
- troca de protocolo
- uso de perfil, modo, cenario e DTC
- OTA online
- uso da credencial fixa do sistema
- integracao com o plugin local do Codex

## 2. Acesso ao simulador

Acesse pelo hostname mDNS ou pelo IP:

```text
http://youobd2.local/
http://192.168.1.9/
```

Pagina de administracao OTA:

```text
http://youobd2.local/ota.html
http://192.168.1.9/ota.html
```

Credencial atual do laboratorio:

- Web/OTA: credencial fixa de operacao
- API: mesma credencial fixa usada na Web

Observacao:

- hostname e manifest OTA continuam editaveis
- login e senha nao sao alterados pela pagina OTA nesta revisao

## 3. Painel principal

O painel principal concentra o controle de protocolo, sensores, perfil, modo, cenario e DTCs.

Observacao:

- a captura abaixo e ilustrativa
- valores e indicadores podem variar conforme o protocolo, perfil e estado atual do simulador

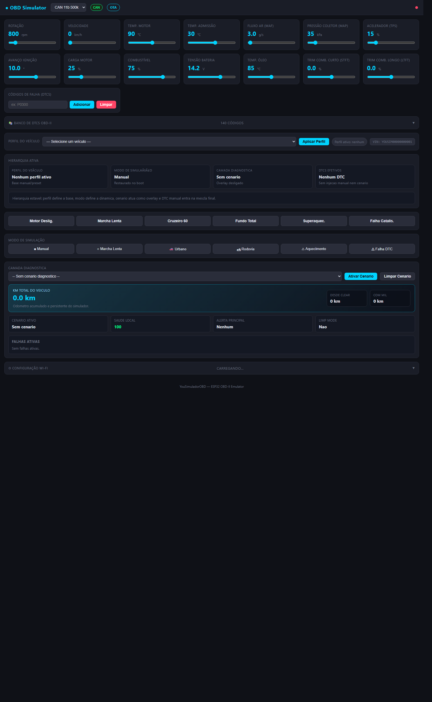
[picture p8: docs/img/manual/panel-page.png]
Painel principal do simulador


### O que existe na tela

- seletor de protocolo no topo
- badge do barramento ativo (`CAN` ou `K-Line`)
- sliders de sensores principais
- banco de DTCs e adicao manual
- selecao de perfil do veiculo
- bloco `Hierarquia Ativa`
- modos de simulacao
- camada diagnostica
- odometro total e metricas de falha

## 4. Logica de operacao

Use esta ordem para trabalhar de forma previsivel:

1. Escolha o protocolo.
2. Aplique o perfil do veiculo.
3. Escolha o modo de simulacao.
4. Ative o cenario diagnostico, se necessario.
5. Injete DTCs manuais so quando o teste exigir.

Regra pratica:

- `Perfil` define a base do carro.
- `Modo` define a dinamica.
- `Camada diagnostica` aplica o overlay de falha.
- `DTC manual` e injecao direta para teste.

## 5. Perfis, modos e cenarios

### Perfil do veiculo

Use para carregar baseline realista de:

- VIN
- protocolo
- comportamento basico
- parametros coerentes por veiculo

### Modo de simulacao

Os modos mais comuns sao:

- `Manual`
- `Marcha Lenta`
- `Urbano`
- `Rodovia`
- `Aquecimento`
- `Falha DTC`

### Camada diagnostica

Use para falhas compostas, por exemplo:

- superaquecimento
- catalisador
- misfire
- anomalias de sensores

## 6. Pagina OTA e configuracao de campo

Na `/ota.html` ficam:

- informacoes do dispositivo
- hostname
- manifest OTA padrao
- status da credencial fixa Web/OTA e API
- intervalo de checagem online

Observacao:

- a captura abaixo mostra a estrutura da pagina
- mensagens de status podem variar conforme autenticacao, rede e checagem OTA

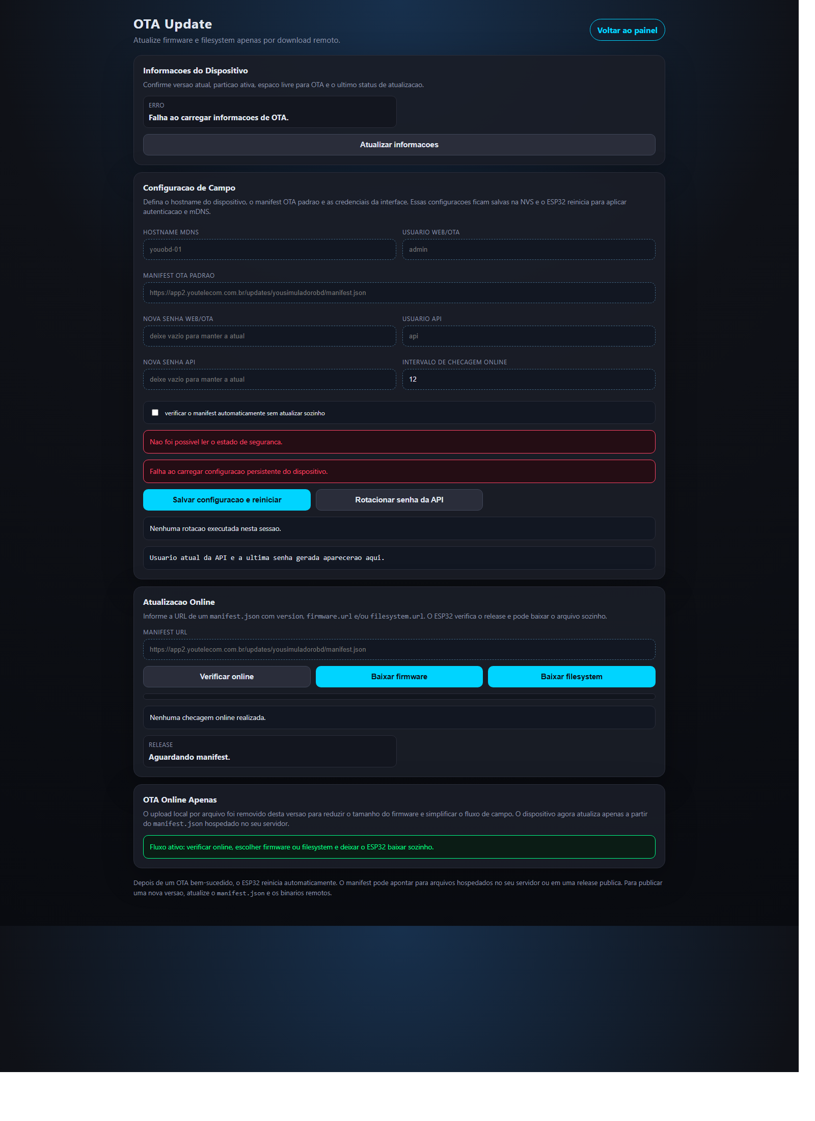
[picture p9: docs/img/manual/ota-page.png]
Pagina OTA e Configuracao de Campo


## 7. Salvar configuracao e reiniciar

Use `Salvar configuracao e reiniciar` quando voce alterar:

- hostname
- manifest OTA
- politica de checagem OTA

Esse fluxo:

- grava em NVS
- agenda reboot
- reaplica mDNS e demais configuracoes persistentes

## 8. Credencial fixa e plugin

Nesta revisao:

- a credencial do sistema e fixa no firmware
- Web/OTA e API usam o mesmo login
- nao existe rotacao de senha pela UI

## 9. Plugin YOU OBD Lab

O plugin serve para:

- preparar cenarios
- consultar o oracle da API
- abrir o app Android
- coletar logcat
- registrar screenshot
- gerar `report.md` e `report.json`

Fluxo do laboratorio com o plugin

### Arquivo local de credenciais do plugin

O plugin le automaticamente:

```text
C:\www\you-obd-lab-plugin\scripts\local-api-credentials.json
```

Formato:

```json
{
  "user": "youobd-core",
  "password": "credencial-fixa-da-bancada"
}
```

Esse arquivo:

- fica fora do Git
- deve refletir a credencial fixa vigente do firmware ou da bancada

## 10. Fluxo recomendado de bancada

### Para validar scanner ou app

1. Escolha o protocolo correto.
2. Aplique o perfil do veiculo.
3. Defina o modo.
4. Ative o cenario, se necessario.
5. Conecte `OBDLink` ou `ELM327`.
6. Teste com `YouAutoCarvAPP2`, `Torque Pro` ou `OBDLink`.

### Para validar com o plugin

1. Confirme a credencial fixa vigente no firmware.
2. Atualize `local-api-credentials.json` se necessario.
3. Rode o runner de bancada.
4. Compare `API`, `OBD real` e `UI/logcat`.

## 11. OTA online

Fluxo recomendado:

1. Abra `/ota.html`.
2. Confirme o `manifest.json`.
3. Use `Verificar online`.
4. Se houver update, escolha:

- `Baixar firmware`
- `Baixar filesystem`

5. Aguarde a gravacao.
6. O ESP32 reinicia automaticamente ao final do OTA.

## 12. Troubleshooting rapido

### Nao consigo entrar na web

- confirme IP ou mDNS
- confirme usuario e senha da credencial fixa Web/OTA
- se o hostname mudou, use o novo `.local`

### API retorna `401`

- confirme a credencial fixa Web/API
- teste em `/api/status`
- confirme que plugin e scripts usam a mesma credencial do firmware

### Plugin parou de validar

- revise `local-api-credentials.json`
- teste `GET /api/status`
- execute o runner com `-SkipPhone -SkipAppLaunch` para smoke test rapido

### OTA nao baixa

- valide a URL do `manifest.json`
- confirme que o ESP32 tem rede
- use `Verificar online` antes do download

## 13. Referencias cruzadas

- [Arquitetura canonica](arquitetura.md)
- [Hardware consolidado](hardware.md)
- [Pinout canonico](pinout.md)
- [Firmware - README local](../firmware/README.md)

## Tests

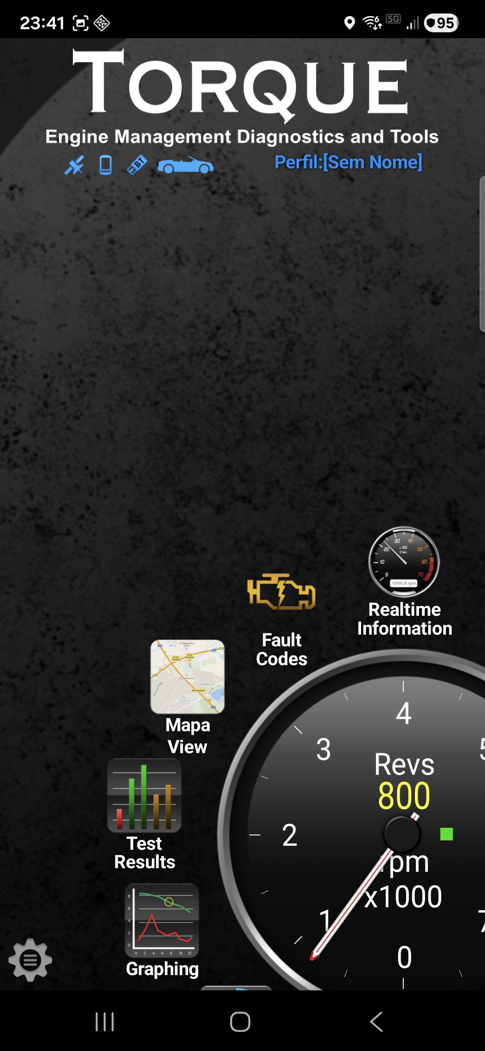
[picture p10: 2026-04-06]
assets/validation/phone_screen.png

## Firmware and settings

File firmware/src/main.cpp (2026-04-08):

#include <Arduino.h>
#include <freertos/FreeRTOS.h>
#include <freertos/semphr.h>
#include <freertos/task.h>
#include <Preferences.h>

#include "config.h"
#include "obd_types.h"
#include "simulation_state.h"
#include "simulation_precedence.h"
#include "vehicle_profiles.h"

void protocol_init(SimulationState* state, SemaphoreHandle_t mutex);
void ui_init(SimulationState* state, SemaphoreHandle_t mutex);
void web_init(SimulationState* state, SemaphoreHandle_t mutex);
void dynamic_init(SimulationState* state, SemaphoreHandle_t mutex);
SimulationState g_sim;
SemaphoreHandle_t g_sim_mutex;

static uint8_t load_saved_protocol(uint8_t fallback_protocol) {
    Preferences prefs;
    prefs.begin("obd", true);
    const uint8_t saved_protocol = prefs.getUChar("proto", 0xFF);
    prefs.end();
    return saved_protocol < PROTO_COUNT ? saved_protocol : fallback_protocol;
}

static bool load_saved_profile_id(char* out, size_t out_size) {
    if (!out || out_size == 0) {
        return false;
    }
    out[0] = '\0';

    Preferences prefs;
    prefs.begin("obd", true);
    String saved_profile = prefs.getString("profile", "");
    prefs.end();

    if (saved_profile.isEmpty()) {
        return false;
    }

    saved_profile.toCharArray(out, out_size);
    return out[0] != '\0';
}

void setup() {
    Serial.begin(115200);
    Serial.println("\n[YouSimuladorOBD] Iniciando...");
    simulation_precedence_reset();

    g_sim_mutex = xSemaphoreCreateMutex();
    configASSERT(g_sim_mutex);

    pinMode(PIN_DIP_0, INPUT);
    pinMode(PIN_DIP_1, INPUT);
    pinMode(PIN_DIP_2, INPUT);
    uint8_t dip = (digitalRead(PIN_DIP_2) << 2)
                | (digitalRead(PIN_DIP_1) << 1)
                |  digitalRead(PIN_DIP_0);
    const uint8_t dip_protocol = (dip < PROTO_COUNT) ? dip : PROTO_CAN_11B_500K;
    const uint8_t saved_protocol = load_saved_protocol(dip_protocol);
    if (PROTO_BOOT_OVERRIDE < PROTO_COUNT) {
        g_sim.active_protocol = PROTO_BOOT_OVERRIDE;
        Serial.printf("[OBD] Protocolo inicial travado em: %s (DIP=%s)\n",
                      protoName(g_sim.active_protocol),
                      protoName(dip_protocol));
    } else {
        g_sim.active_protocol = saved_protocol;
        Serial.printf("[OBD] Protocolo inicial: %s (DIP=%s)\n",
                      protoName(g_sim.active_protocol),
                      protoName(dip_protocol));
    }

    char saved_profile_id[sizeof(g_sim.profile_id)] = {};
    if (load_saved_profile_id(saved_profile_id, sizeof(saved_profile_id))) {
        const VehicleProfile* saved_profile = findProfile(saved_profile_id);
        if (saved_profile) {
            applyVehicleProfile(g_sim, *saved_profile);
            simulation_precedence_set_notice(SIM_NOTICE_PROFILE_RESTORED);
            Serial.printf("[VEHICLE] Perfil restaurado: %s %s (%s)\n",
                          saved_profile->brand,
                          saved_profile->model,
                          saved_profile->year);
        } else {
            Serial.printf("[VEHICLE] Perfil salvo invalido ignorado: %s\n", saved_profile_id);
        }
    }

    pinMode(PIN_LED_BUILTIN, OUTPUT);
    pinMode(PIN_LED_TX, OUTPUT);

    protocol_init(&g_sim, g_sim_mutex);
    ui_init(&g_sim, g_sim_mutex);
    web_init(&g_sim, g_sim_mutex);
    dynamic_init(&g_sim, g_sim_mutex);

    Serial.println("[YouSimuladorOBD] Tasks iniciadas.");
}

void loop() {
    digitalWrite(PIN_LED_BUILTIN, HIGH);
    vTaskDelay(pdMS_TO_TICKS(500));
    digitalWrite(PIN_LED_BUILTIN, LOW);
    vTaskDelay(pdMS_TO_TICKS(500));
}

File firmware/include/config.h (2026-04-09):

#pragma once

#include <cstdint>

// ============================================================================
// YouSimuladorOBD - config.h
// Todos os pinos e constantes centrais do firmware em um unico lugar.
// Hardware: ESP32 38-pin + placa expansao com bornes.
// ============================================================================

// -- CAN / TWAI (usa SN65HVD230 - 3.3V nativo) -------------------------------
constexpr int PIN_CAN_TX = 4;
constexpr int PIN_CAN_RX = 5;

// -- K-Line (ISO 9141-2 / KWP2000) via UART1 ---------------------------------
constexpr int PIN_KLINE_TX = 17;
constexpr int PIN_KLINE_RX = 16;
constexpr int KLINE_UART_NUM = 1;
constexpr uint32_t KLINE_BAUD = 10400;

// -- Display OLED SH1107 128x128 (I2C) ---------------------------------------
constexpr int PIN_OLED_SDA = 21;
constexpr int PIN_OLED_SCL = 22;
constexpr uint8_t OLED_I2C_ADDR = 0x3C;

// -- Botoes (pull-up interno, ativo em LOW) ----------------------------------
constexpr int PIN_BTN_PREV = 32;
constexpr int PIN_BTN_NEXT = 33;
constexpr int PIN_BTN_UP = 25;
constexpr int PIN_BTN_DOWN = 26;
constexpr int PIN_BTN_SELECT = 27;
constexpr int PIN_BTN_PROTOCOL = 18;

// -- Encoder rotativo KY-040 -------------------------------------------------
constexpr int PIN_ENC_A = 14;
constexpr int PIN_ENC_B = 13;
constexpr int PIN_ENC_SW = 19;

// -- DIP Switch (somente entrada - GPIO 34-39) -------------------------------
constexpr int PIN_DIP_0 = 34;
constexpr int PIN_DIP_1 = 35;
constexpr int PIN_DIP_2 = 36;

// -- LEDs de status ----------------------------------------------------------
constexpr int PIN_LED_BUILTIN = 2;
constexpr int PIN_LED_TX = 23;

// ============================================================================
// Protocolos OBD-II
// ============================================================================
constexpr uint8_t PROTO_CAN_11B_500K = 0;
constexpr uint8_t PROTO_CAN_11B_250K = 1;
constexpr uint8_t PROTO_CAN_29B_500K = 2;
constexpr uint8_t PROTO_CAN_29B_250K = 3;
constexpr uint8_t PROTO_ISO9141 = 4;
constexpr uint8_t PROTO_KWP_5BAUD = 5;
constexpr uint8_t PROTO_KWP_FAST = 6;
constexpr uint8_t PROTO_COUNT = 7;
constexpr uint8_t PROTO_BOOT_OVERRIDE = 0xFF;

inline const char* protoName(uint8_t p) {
    switch (p) {
        case 0:
            return "CAN 11b 500k";
        case 1:
            return "CAN 11b 250k";
        case 2:
            return "CAN 29b 500k";
        case 3:
            return "CAN 29b 250k";
        case 4:
            return "ISO 9141-2";
        case 5:
            return "KWP 5-baud";
        case 6:
            return "KWP Fast";
        default:
            return "???";
    }
}

// ============================================================================
// IDs CAN OBD-II
// ============================================================================
constexpr uint32_t OBD_CAN_FUNC_11B = 0x7DF;
constexpr uint32_t OBD_CAN_PHYS_11B = 0x7E0;
constexpr uint32_t OBD_CAN_RESP_11B = 0x7E8;
constexpr uint32_t OBD_CAN_FUNC_29B = 0x18DB33F1;
constexpr uint32_t OBD_CAN_RESP_29B = 0x18DAF110;

// ============================================================================
// Wi-Fi / Web
// ============================================================================
constexpr uint8_t MAX_WIFI_NETS = 4;

// -- Modo AP (fallback / standalone) -----------------------------------------
constexpr char AP_SSID[] = "OBD-Simulator";
constexpr char AP_PASSWORD[] = "obd12345";
constexpr char AP_IP[] = "192.168.4.1";

// -- Modo STA ----------------------------------------------------------------
constexpr char STA_SSID[] = "YOU_AUTO_CAR_2.4";
constexpr char STA_PASSWORD[] = "cd1aamss";

constexpr char STA_STATIC_IP[] = "";
constexpr char STA_GATEWAY[] = "";
constexpr char STA_SUBNET[] = "";
constexpr char STA_DNS1[] = "";
constexpr char STA_DNS2[] = "";

// -- Geral -------------------------------------------------------------------
// Defaults de fabrica. Hostname e manifesto OTA podem ser sobrescritos via
// interface protegida e ficam salvos na NVS.
// As credenciais Web/API desta revisao sao fixas no firmware.
constexpr char MDNS_NAME[] = "youobd";
constexpr char APP_VERSION[] = "2026.04.09.2";
constexpr char OTA_MANIFEST_URL[] =
    "https://app2.youtelecom.com.br/updates/yousimuladorobd/manifest.json";
constexpr char WEB_AUTH_USER[] = "youobd-core";
constexpr char WEB_AUTH_PASSWORD[] = "YouOBD.RevA@2026#Core";
constexpr char API_AUTH_USER[] = "youobd-core";
constexpr char API_AUTH_PASSWORD[] = "YouOBD.RevA@2026#Core";
constexpr uint16_t WEB_PORT = 80;
constexpr uint32_t WS_BROADCAST_MS = 500;
constexpr uint32_t OTA_HTTP_TIMEOUT_MS = 15000;

// -- Modos Wi-Fi (prefixo CFG_ evita conflito com esp_wifi_types.h) ----------
constexpr uint8_t CFG_WIFI_AP = 0;
constexpr uint8_t CFG_WIFI_STA = 1;
constexpr uint8_t CFG_WIFI_AP_STA = 2;
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

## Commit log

2026-04-01 Initial commit — YouSimuladorOBD v2.0
    ESP32 OBD-II Simulator completo:
    - 7 protocolos: CAN 11b/29b 500k/250k, ISO9141, KWP2000, J1850
    - 22 perfis de veículo (Fiat, VW, Chevrolet, Ford, Toyota, Honda, Hyundai, Renault)
    - 12 parâmetros simulados (RPM, velocidade, temps, MAF, MAP, etc.)
    - Interface Web SPA via LittleFS + WebSocket tempo real
    - API REST completa: params, DTCs, presets, perfis, Wi-Fi
    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
2026-04-01 fix: scan Wi-Fi em modo AP puro
    Quando STA falha e o ESP32 cai para WIFI_AP, o rádio STA fica
    desligado e WiFi.scanNetworks() retorna -2 (erro), exibindo lista
    vazia na UI. Agora o task_wifi_scan habilita WIFI_AP_STA antes do
    scan e restaura WIFI_AP ao terminar se não houver conexão STA ativa.
2026-04-01 fix: Wi-Fi scan resiliente em modo AP puro
    - index.html: retry automático no pollScan (até 8 tentativas) para
    absorver erros de rede transitórios durante o scan de redes Wi-Fi
    - web_server.cpp: fallback STA→AP agora usa WIFI_AP_STA em vez de
    WIFI_AP, mantendo o rádio STA ativo para que o scan funcione sem
    precisar de troca de modo temporária
2026-04-01 feat: 4 novos PIDs, fix DTC individual, alertas e badge protocolo
    Firmware:
    - simulation_state.h: adiciona battery_voltage, oil_temp_c, stft_pct,
    ltft_pct; atualiza todos os 6 presets com valores coerentes
    - mode01_handler.cpp: suporte a PIDs 0x06 (STFT), 0x07 (LTFT),
    0x40 (bitmask 41-60), 0x42 (tensão bateria), 0x5C (temp. óleo);
    bitmask 0x00 atualizado de 0x18 para 0x1E
    - web_server.cpp: novos campos no stateToJson, handle_post_params e
    on_ws_event; endpoint POST /api/dtcs/remove (remove DTC individual)
    Web UI:
    - index.html: 4 novos sliders (bateria, óleo, STFT, LTFT); badge
    CAN/K-Line no header; alertas visuais (vermelho) para valores fora
    de range; removeDtc corrigido —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
    [simulation_state.h]
2026-04-01 fix: scan Wi-Fi assíncrono para funcionar em modo STA conectado
    O scan síncrono (WiFi.scanNetworks(false)) trava indefinidamente quando
    o ESP32 está em modo WIFI_STA com conexão ativa. Troca para scan
    assíncrono com poll (500ms) + timeout de 15s.
    Stack da task: 4096 → 8192 bytes (evita stack overflow durante scan).
    Prioridade: 2 → 1 (evita interferência com o driver Wi-Fi conectado).
2026-04-01 feat: troca display SSD1306 128x64 → SH1107 128x128
    - platformio.ini: substitui Adafruit SSD1306 por Adafruit SH110X
    - config.h: atualiza comentário do display
    - ui_init.cpp: migração completa para Adafruit_SH1107
    · Objeto: Adafruit_SH1107(128, 128, &Wire)
    · begin(addr, reset=false) sem pino reset
    · setRotation(0) + setContrast(0xFF)
    · Cores SH110X_WHITE/BLACK
    · Linha separadora com drawFastHLine
    · 8 parâmetros visíveis por tela (antes: 4) em 2 páginas
    · 16 parâmetros navegáveis incluindo bateria, óleo, STFT, LTFT
    · adjustParam() estendido para novos campos
    · Footer com indicador de página (P.1/2)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
    [config.h, ui_init.cpp]
2026-04-01 fix/docs: footer OLED corrigido + doc atualizada para SH1107 128x128
    - ui_init.cpp: footer ajustado para caber em 21 chars
    · Não editando: "OK=edit p.1/2"
    · Editando: "UP/DN=ajust OK=sair"
    - docs/07-ui-controls.md: layout atualizado para 128x128
    · ASCII art das 2 páginas de 8 parâmetros
    · Referência à foto docs/img/oled_sh1107_funcionando.jpg
    · Tabela de ligação I2C (SDA/SCL pinout)
    · Tabela de passos com os 16 parâmetros (incluindo novos)
    · Layout de pixels y=0..127 documentado
    - docs/img/: diretório criado para fotos do hardware
    [ui_init.cpp]
2026-04-01 fix: elimina flickering do OLED SH1107
    Duas causas e duas correções:
    1. I2C 100kHz → 400kHz (Fast Mode)
    Wire.setClock(400000UL) após Wire.begin()
    128×128px = 2048 bytes: tempo de frame 164ms → 41ms
    Reduz o tempo visível de tela em branco entre frames
    2. Redraw condicional (dirty-check com memcmp)
    Compara SimulationState + cursor + modo edição com snapshot anterior
    Só chama render()+display() quando algo realmente mudou
    Loop de 50ms mantido para polling de botões/encoder responsivo
    [ui_init.cpp]
2026-04-01 fix(wifi): corrige scan de redes no modo STA conectado
    - Registra /api/wifi/scan antes de /api/wifi para evitar prefix-match
    no ESPAsyncWebServer (rota mais especifica deve vir primeiro)
    - Troca scanNetworks(async=true) por scan sincrono na task dedicada:
    o modo async retornava 0 redes imediatamente em modo STA conectado;
    o scan sincrono bloqueia apenas a task wifi_scan (~4s) enquanto o
    web server permanece responsivo em outra task FreeRTOS
    - Validado no browser: 4 redes encontradas com SSID, RSSI e icone lock
2026-04-01 docs: atualiza hardware BOM e pinout com componentes reais recebidos
    - BOM: adiciona placa expansao ESP32 38-pin com bornes
    - BOM: adiciona 5x fenolite dupla face 6x8cm + tabela de distribuicao
    - BOM: corrige regulador AMS1117 -> LM2596 step-down 3A
    - BOM: corrige display SSD1306 128x64 -> SH1107 128x128
    - BOM: corrige botoes 3-4 -> 6 botoes (PREV/NEXT/UP/DOWN/SELECT/PROTO)
    - BOM: substitui L9637D por transistor NPN discreto (componente real)
    - BOM: adiciona conector OBD-II femea 16 pinos com chicote
    - Pinout: atualiza K-Line de L9637D para circuito NPN discreto
    - Pinout: corrige OLED SSD1306 -> SH1107 128x128
    - Hardware: adiciona nota de verificacao de cores do chicote OBD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
2026-04-01 docs: adiciona fonte 12V 2.5A ao BOM e secao de consumo
    - BOM: fonte 12V 2,5A para alimentacao em bancada
    - Alimentacao: tabela de consumo estimado por componente (~320mA @ 5V)
    - Nota: fonte substitui OBD pino 16 durante desenvolvimento
2026-04-01 docs: substitui botoes avulsos por modulo 8 Push Buttons V1.1
2026-04-01 fix(ui): corrige duplo disparo e reduz passos dos botoes
    - Remove logica fell()||read()==LOW que causava 2+ passos por clique
    - Implementa hold-repeat: 1 passo no press, repeticao apos 500ms
    a cada 150ms enquanto segurado (sem duplo disparo em clique simples)
    - Passos reduzidos: RPM 50->10, Vel/Temp/TPS/Carga/Comb/Oleo 5->1,
    Avanco 1.0->0.5, STFT/LTFT 0.8->0.5 por passo
    - Debounce aumentado de 50ms para 80ms para modulo 8 Push Buttons
    [config.h, ui_init.cpp]
2026-04-01 feat(sim): implementa modo dinâmico com 6 cenários de simulação
    Adiciona motor de física (dynamic_engine) que atualiza o SimulationState
    a cada 100ms com comportamento realista de carro: IDLE, URBAN, HIGHWAY,
    WARMUP e FAULT. Modo STATIC mantém valores manuais inalterados.
    - dynamic_engine.cpp: máquina de estados, física de RPM/MAF/MAP/temperatura
    - simulation_state.h: enum SimMode + campo sim_mode em SimulationState
    - web_server.cpp: sim_mode no JSON, POST /api/mode, WS type "mode"
    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
2026-04-01 feat(dtc): banco de 140 DTCs OBD-II com busca e encoding correto B/C/U
    Adiciona painel expansível com 140 códigos de falha (P/B/C/U) organizados
    em 10 categorias, busca em tempo real por código ou descrição, botão +
    com feedback visual ✓, e bloqueio automático ao atingir limite de 8 DTCs.
    Corrige codificação OBD-II para prefixos B/C/U: B0001→0x8001,
    C0035→0x4035, U0100→0xC100, garantindo bytes corretos no Mode 03.
    Todas as funções de serialização/parsing de DTC atualizadas.
2026-04-02 fix(sim): reescreve motor dinâmico com física calibrada em dados reais
    Problemas corrigidos:
    - WARMUP: temperatura parava em ~27°C (incremento muito lento para demo).
    Agora usa curva de 4 fases comprimida para ~3 min: termost. fechado
    (20→55°C rápido), abrindo (55→80°C), radiador ativo (80→90°C lento),
    regulação termostática (90-93°C oscilando). Oil lags coolant ~12°C.
    - FAULT: DTCs só apareciam após 15-35s. Agora P0300+P0301+P0304 são
    definidos imediatamente ao entrar no modo. RPM irregular com quedas
    de até -400 RPM simulando misfire real. STFT +15-18%.
    - Todos os modos: ruído aleatório por tick causava flickering nos
    valores. Substituído por Wander (ra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
    [dynamic_engine.cpp]
2026-04-02 docs: adiciona documentação canônica do modo dinâmico e banco de DTCs
    - docs/10-dynamic-simulation.md: novo documento completo com valores
    calibrados por modo (idle/urban/highway/warmup/fault), curva de
    aquecimento em 4 fases, modelo de ruído Wander+EMA, fórmulas de
    física (MAF/MAP/ignição/IAT), tabela do banco de 140 DTCs, e API
    - docs/01-overview.md: adiciona simulação dinâmica ao fluxo de
    operação e DynamicEngine à camada de aplicação
    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
2026-04-02 fix(wifi): corrige AP não iniciando quando STA falha na conexão
    WiFi.begin() deixa o driver em estado de conexão pendente. Sem
    WiFi.disconnect(true) antes de trocar para AP_STA, o softAP não
    consegue subir. Agora: disconnect → delay 200ms → mode(AP_STA)
    → softAP. Garante rede "OBD-Simulator" visível quando sem Wi-Fi.
2026-04-02 feat(bt): emulador ELM327 via Bluetooth SPP para apps OBD
    Adiciona Bluetooth Classic SPP que emula adaptador ELM327 v1.5.
    Apps como Torque Pro, OBD Auto Doctor e Car Scanner podem conectar
    via Bluetooth e ler dados do simulador como se fosse um carro real.
    O BT roda em paralelo com CAN/K-Line e WebUI, compartilhando o
    mesmo SimulationState via mutex. Nome: "OBD-Simulator", PIN: 1234.
    Comandos AT implementados: Z, I, E0/E1, H0/H1, L0/L1, S0/S1,
    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
2026-04-02 feat(wifi): suporte a múltiplas redes salvas com scan automático
    Funciona como celular/notebook: salva até 4 redes WiFi na NVS e
    no boot faz scan para conectar automaticamente na melhor rede
    conhecida (maior RSSI). Se nenhuma encontrada, sobe AP fallback.
    - wifi_start(): scan → match saved → connect best → AP fallback
    - NVS multi-rede: s0/p0/i0/g0 ... s3/p3/i3/g3 + migração formato antigo
    - GET /api/wifi: retorna lista de redes salvas + status conexão
    - POST /api/wifi: adiciona/atualiza rede (por SSID) + reboot
    - POST /api/wifi/remove: remove rede por índice
    - WebUI: painel "Redes Salvas" com indicador conectado + botão remover
    - Cada rede pode ter IP estático ou DHCP indepen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
    [config.h]
2026-04-02 Fix ESP32 Wi-Fi web access stability
    [config.h, main.cpp]
2026-04-03 feat(can): validar bancada e corrigir runtime switch
    [can_protocol.cpp, config.h, kline_protocol.cpp]
2026-04-03 docs(kline): adicionar guia de montagem com L9637D
2026-04-03 docs(kline): adicionar guia visual de montagem
2026-04-03 fix(vin): use valid 17-char default vin
    [config.h, simulation_state.h]
2026-04-04 feat(diagnostics): add freeze frame history api
2026-04-05 feat: finalize hardware handoff and CAD starter
    [bench_case_revA_base.FCStd, bench_case_revA_base.step, bench_case_revA_base.stl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]
2026-04-05 feat: add kicad bootstrap and engineer package
    [YouSimuladorOBD_RevA.kicad_sch, bench_case_revA_lid_ui.FCStd, bench_case_revA_lid_ui.step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]
2026-04-05 feat: persist simulator state and carrier handoff
    [bom-rev-a.csv, esp32-devkit38-carrier-reference.csv, esp32_core.kicad_sch]
2026-04-06 chore(repo): move validation artifacts and isolate legacy schematic files
2026-04-06 docs(hw): add consolidated hardware, pinout, schematic, BOM, and PCB layout docs
    [bom-preliminar.csv]
2026-04-06 docs(hw): recommend protection parts for RevA
    [bom-preliminar.csv]
2026-04-06 docs: mark KWP 5-baud as validated and shift focus to PCB productization
2026-04-06 docs(img): add handoff diagrams for pcb vendor
2026-04-07 docs(lab): document simulator api auth for validation flows
2026-04-07 fix(auth): lock simulator to a single fixed credential
    [config.h]
2026-04-08 Align RevA pinout and retire legacy handoff
    [bom-preliminar.csv, bom-rev-a.csv, esp32_core.kicad_sch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]
2026-04-08 Consolidate docs set and finalize Wi-Fi config updates
    [YouSimuladorOBD_RevA.kicad_sch, esp32_core.kicad_sch, power_input.kicad_sch]
2026-04-09 fix(ota): sincronizar estado online e preparar release 2026.04.09.2
    [config.h]
